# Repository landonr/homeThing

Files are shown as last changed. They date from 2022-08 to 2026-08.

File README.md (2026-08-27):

<h1 align = "center">homeThing Remote ⚙️</h1>
<h5 align = "center">(esphome remote)</h1>
<p align="center">


</p>

#### homeThing is a collection of software and hardware for creating universal remotes that control smart home devices.
There are 3 components that belong to homeThing: the case and circuit board, the menu system code, and the code to control smart home devices
- <a href="#hardware-">Hardware specific for smart home remotes that's open source, customizable, and 3D printable.</a>
- <a href="#homething-menu-">Menu system for ESP32 devices focused on controlling smart home devices similar to an iPod's menu.</a>
- [ESPHome Components for controlling Home Assistant devices.](https://github.com/landonr/esphome-components)

<br>
<div align="center">
	<h2><a href="https://github.com/landonr/homething-c6">Check out the next-generation homeThing C6</a></h2>
</div>
<br>

### Learn More
 - [Get Started](GettingStarted.md) - Learn how to build your own remote
 - [Discord](https://discord.gg/BX6ZtGKHTy) - support / chat with the community and the team
 - [Instagram](https://www.instagram.com/homething.io/) - Follow us on Instagram for updates and new products
 - [Website](https://homething.io) - Check out our website for more information

<div align="center">
	<h3>
	<a href="https://youtu.be/5bx5w-n5c0Y">
		Demo Video
		<br>Demo Video - Watch on YouTube 🎬
	</a>
	</h3>
</div>

# Hardware 💪
We designed the two remotes below to be ideal for controlling smart home devices without a touch screen. They are both battery-powered but can also be plugged into USB and left in one place. The first remote was based on a Lilygo TDisplay. We moved on to building the homeThing S3 because the original device had slow performance, lacked buttons, and had challenges with assembly.
<table>
  <tr>
    <th>
	    <h3>TDisplay homeThing</h3>
    </th>
    <th>
	    <h3>TDisplay S3 homeThing</h3>
	    <a href="https://github.com/landonr/homeThing/tree/main/Case%20Design/tdisplay-s3">More Info</a><br>
    </th>
  </tr>
  <tr>
    <td></td>
    <td></td>

  </tr>
  <tr>
	  <td>Not available for purchase</td>
	  <td><a href="https://homething.io/Buy">Buy fully assembled, ships within 3 business days from 🇨🇦</a></td>
  </tr>
  <tr>
    <td><a href="https://www.pcbway.com/project/shareproject/homeThing_V1_3_e3572f8f.html">Order Case from PCBWay</a></td>
    <td>
      <a href="https://www.pcbway.com/project/shareproject/homeThing_S3_2b3ac3ac.html">Order parts or fully assembled from PCBWay</a>
    </td>
  </tr>
  <tr>
    <td><a href="https://github.com/landonr/homeThing/tree/main/Case%20Design">Case 3D Files</a></td>
    <td><a href="https://github.com/landonr/homeThing/tree/main/Case%20Design">Case 3D Files</a></td>
  </tr>
  <tr>
    <td><a href="tdisplay-ipod.yaml">ESPHome Config</a></td>
    <td><a href="tdisplay-s3.yaml">ESPHome Config</a></td>
  </tr>
  <tr>
  	<td>
	<h4>Features</h4>
	<ul>
		<li>Based on Lilygo TTGo TDisplay, an ESP32 with integrated screen
		<li>Low cost remote with minimal parts</li>
		<li>Scroll wheel and 2 configurable buttons</li>
		<li>USB-C Charging</li>
		<li>3D Printable case with 3 parts</li>
	</ul>
	</td>
  	<td>
	<h4>Features</h4>
	<ul>
		<li>Based on Lilygo TDisplay S3, an ESP32 S3 with integrated screen</li>
		<li>Faster processor and larger display</li>
		<li>Custom PCB for easier setup</li>
		<li>IR Blaster for controlling infrared devices</li>
		<li>Interal microphone for Voice Assistant</li>
		<li>Scroll wheel and 5 configurable buttons</li>
		<li>USB-C Charging</li>
		<li>3D Printable case with 2 parts</li>
	</ul>
	</td>
  </tr>
</table>

We made a couple of custom devices for running homeThing, but it can also run on almost any ESP32 such as,
- M5Stack Fire
- M5Stick C
- Lilygo T-Display T4
- Lilygo T-Display TTGO
- Lilygo T-Display S3
# homeThing Menu 📝
### ESPHome menu system that requires minimal config. Features apps which have custom UIs
|t-display demo|m5stack fire demo|lilygo T4 demo|
|--|--|--|
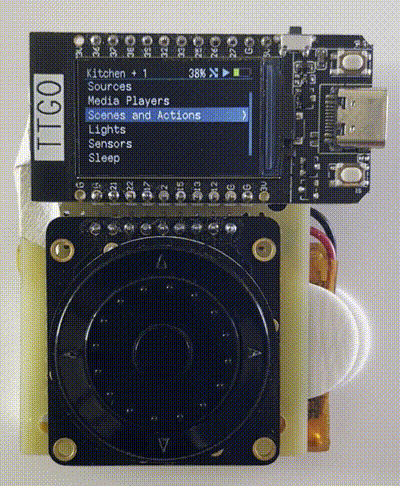
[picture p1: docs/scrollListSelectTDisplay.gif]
Scroll Demo Gif
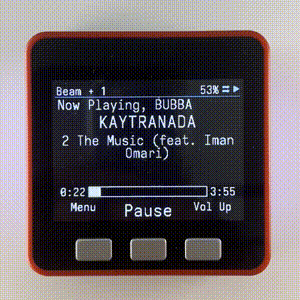
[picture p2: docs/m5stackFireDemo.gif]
Scroll List Fire Demo Gif
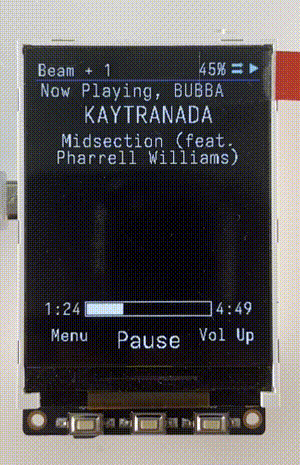
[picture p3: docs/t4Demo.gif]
Lilygo T4 Demo
|||

- Scroll through list and press center to select
- With a scrollwheel the top button goes back
- On M5Stack going up past the top of the list will go back
- A scroll bar appears if list extends past the screen. 
- Screen returns to now playing after display sleeps
    - Display sleeps after 10s of idle. Device sleeps after 2h of idle 💤
- Font size and UI size is adjustable in yaml 🔨
- Simple yaml configuration. all of the complicated code is included in other files 🛠
- Header is always shown at the top with info about the current state

## Apps
### Now playing screen ⏯
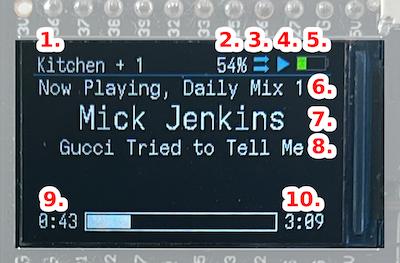
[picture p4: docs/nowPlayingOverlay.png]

<ul>
<li>Control media players using the scroll wheel buttons</li>
<li>Scroll for volume using the scroll wheel</li>
</ul>

|Music|TV|
|--|--|
|<ul><li>Control smart speakers like Sonos, Spotify, or Google Home</li><li>Change source from Spotify playlists, Sonos Favorites, and custom lists</li><li>Manage speaker groups</li></ul>|<ul><li>Menu navigation such as up, down, left, right, select (with scroll wheel)</li><li>Power, back, home, pause in second menu</li><li>Change source from tv source list</li><li>Optional soundbar support</li></ul>|

### IR Remote
<ul>
<li>Custom UI and buttons to control infrared cat toys</li>
</ul>

### Games
<ul>
<li>Snake</li>
<li>Breakout</li>
</ul>

# Mentions
- Home Assistant Voice Contest - Best Starting Guide https://www.home-assistant.io/blog/2024/03/16/voice-assistant-community-contest-winners-annoucement/
- Hackaday https://hackaday.com/2022/09/08/scroll-through-esphome-with-ipod-style-click-wheel/
- Hackster https://www.hackster.io/news/ipod-style-esphome-remote-3ca38edab2b4
- Reddit post https://www.reddit.com/r/homeassistant/comments/x59dcp/i_built_an_ipod_style_esphome_remote_for_home/
- Self Hosted - Episode 80 - Solving Whole Home Audio (around 30:00) https://selfhosted.show/80 

# Includes
- <a href="https://esphome.io/">ESPHome</a>
- <a href="https://github.com/be5invis/Iosevka">Iosevka Font</a>
- [@ssieb](https://github.com/ssieb)'s <a href="https://github.com/ssieb/custom_components/tree/master/components/ip5306">IP5306 esphome component</a>
- <a href="https://github.com/landonr/esphome-components">homeThing ESPHome Components</a>

# Sponsorship



## [PCBWay](https://pcbway.com/g/Xymq6O "PCBWay") sponsors 3D Printing and PCB assembly costs on this project during the prototyping phase! 
If you are interested in their awesome fabrication services please check them out.&nbsp; They offer 

3D prototyping,&nbsp;PCB design and assembly, as well as CNC metal fabrication.&nbsp; Costs are reasonable and the quality is as good as it gets.&nbsp; Thank you PCBWay for sponsoring us and other fun projects!<br><br>

## [cargo](https://cargo.site/ "cargo.site") sponsors our website!

They make it super easy to keep things pretty and up to date! It’s honestly so much easier than managing our own site, highly recommended!

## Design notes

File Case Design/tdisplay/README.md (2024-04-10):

<table>
  <tr>
    <th>TDisplay homeThing</th>
  </tr>
  <tr>
    <td></td>
  </tr>
  <tr>
    <td><a href="https://www.pcbway.com/project/shareproject/homeThing_V1_3_e3572f8f.html">Order Case from PCBWay</a></td>
  </tr>
  <tr>
    <td><a href="https://github.com/landonr/homeThing/tree/main/Case%20Design">Case 3D Files</a></td>
  </tr>
  <tr>
    <td><a href="tdisplay-ipod.yaml">ESPHome Config</a></td>
  </tr>
  <tr>
  	<td>
	<h4>Features</h4>
	<ul>
	<li>Low cost remote with minimal parts</li>
	<li>Scroll wheel and 2 configurable buttons</li>
	<li>USB-C Charging</li>
	<li>3D Printable case with 3 parts</li>
	</ul>
	</td>
  </tr>
  <tr>
  	<td>
	<h4>Parts</h4>
	<ul>
	<li><a href="https://www.adafruit.com/product/5001">Adafruit ANO Directional Navigation and Scroll Wheel Rotary Encoder</a></li>
	<li><a href="https://www.adafruit.com/product/5221">Adafruit ANO Rotary Navigation Encoder Breakout PCB</a></li>
	<li><a href="https://leeselectronic.com/en/product/88345-battery-rechargeable-li-poly-37v-1100mah-jst-zh.html">1100mah lipo</a></li>
	</ul>
	</td>
  </tr>
</table>

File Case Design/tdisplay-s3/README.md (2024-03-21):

<h2>TDisplay S3 homeThing</h2>

<table>
    <tr>
        <th>TDisplay S3<br>homeThing Case</th>
        <th>homeThing S3<br>Circuit Front</th>
        <th>homeThing S3<br>Circuit Back</th>
    </tr>
        <td>
            
        </td>
        <td>
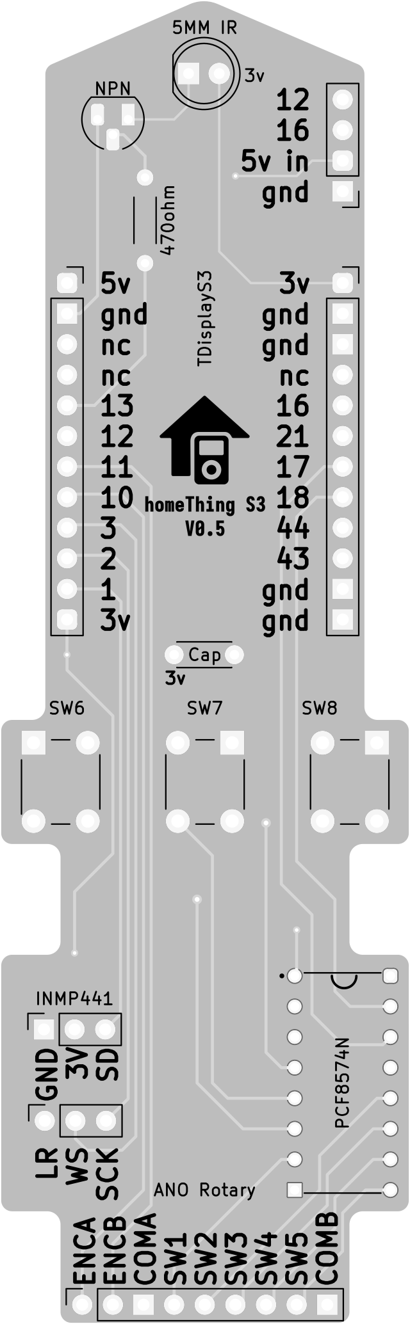
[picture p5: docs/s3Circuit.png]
            
        </td>
        <td>
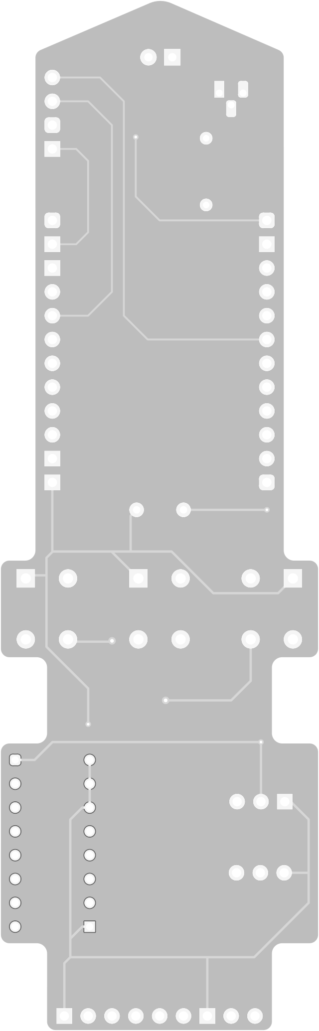
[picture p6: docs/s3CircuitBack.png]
            
        </td>
    </tr>
</table>

<h2>Order</h2>
<a href="https://www.pcbway.com/project/shareproject/homeThing_S3_2b3ac3ac.html">Order Case and PCB from PCBWay</a>

<h2>Case 3D Files</h2>
There's a different file for for the front part FDM printers. This doesn't have extruded buttons so it can print flat without supports
<table>
    <tr>
        <th>Front</th>
        <th>Back</th>
    </tr>
    <tr>
        <td><a href="s3 case front sls.stl">s3 case front sls.stl</a></td>
        <td><a href="s3 case back.stl">s3 case back.stl</a></td>
    </tr>
    <tr>
        <td><a href="s3 case front fdm.stl">s3 case front fdm.stl</a></td>
    </tr>
</table>

<h2>Circuit</h2>
<a href="gerber/">Gerber Files</a>

<h2>ESPHome Config</h2>
<a href="tdisplay-s3.yaml">tdisplay-s3.yaml</a>

<h2>Parts</h2>
<table>
    <tr>
        <th>Name</th>
        <th>Description</th>
    </tr>
    <tr>
        <td><a href="https://www.adafruit.com/product/5221">Custom PCB</a></td>
        <td>Custom PCB for TDisplay S3</td>
    </tr>
    <tr>
        <td><a href="https://www.lilygo.cc/en-ca/products/t-display-s3?variant=42351558590645">TDisplay S3 (Soldered Pin)</a></td>
        <td>TDisplay S3 with soldered pin</td>
    </tr>
    <tr>
        <td><a href="https://www.adafruit.com/product/5001">Adafruit ANO Directional Navigation and Scroll Wheel Rotary Encoder</a></td>
        <td>Directional navigation and scroll wheel rotary encoder</td>
    </tr>
    <tr>
        <td><a href="https://www.adafruit.com/product/5221">Adafruit ANO Rotary Navigation Encoder Breakout PCB</a></td>
        <td>Rotary navigation encoder breakout PCB</td>
    </tr>
    <tr>
        <td><a href="https://www.aliexpress.us/item/32962426410.html">INMP441</a></td>
        <td>INMP441 i2s Microphone</td>
    </tr>
    <tr>
        <td><a href="https://leeselectronic.com/en/product/71446-ic-i-o-expander-for-i2c-8bit-pcf8574p.html">PCF8574n</a></td>
        <td>GPIO extender for I2C 8-bit</td>
    </tr>
    <tr>
        <td><a href="https://leeselectronic.com/en/product/91581-91581RESISTORS14W470OHM110PCS.html">470ohm resistor</a></td>
        <td>470ohm resistor</td>
    </tr>
    <tr>
        <td><a href="https://leeselectronic.com/en/product/844-polyester-cap-50v-01uf-4pcs.html">0.1uF capacitor</a></td>
        <td>0.1uF capacitor</td>
    </tr>
    <tr>
        <td><a href="https://www.aliexpress.com/item/32835179410.html">3.7V 7x20x50mm 700mAh Lipo</a></td>
        <td>3.7V 7x20x50mm 700mAh Lipo</td>
    </tr>
    <tr>
        <td><a href="https://leeselectronic.com/en/product/31231-tack-switch-6x6x10mm.html">10mm Push Button</a></td>
        <td>10mm Push Button</td>
    </tr>
    <tr>
        <td><a href="https://leeselectronic.com/en/product/6049-6049BOLTM25100PCS.html">M2.5x8mm screws</a></td>
        <td>M2.5x8mm screws</td>
    </tr>
    <tr>
        <td><a href="https://leeselectronic.com/qc/product/7174-7174TRANSISTOR2N2222MPS2222ANPN5.html">2N2222 Transistor</a></td>
        <td>2N2222 Transistor</td>
    </tr>
</table>

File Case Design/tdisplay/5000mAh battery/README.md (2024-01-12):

# 3D Case Design
## _Designed to fit a 5000 mAh battery_

Main components can be seen in the "main components.jpg" photo.
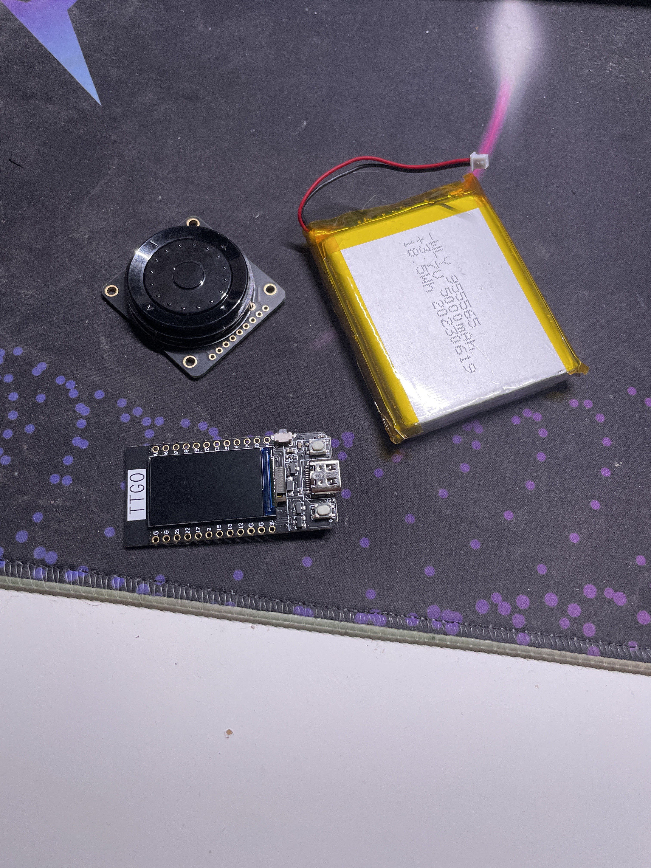
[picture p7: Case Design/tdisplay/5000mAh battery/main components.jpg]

Components list:
- 5000 mAh battery (check the form factor in "main components.jpg" photo; it was bought from a local store so i'm note sure a link would be useful)
- Lilygo T-Display TTGO
- Adafruit ANO Directional Navigation and Scroll Wheel Rotary Encoder [https://www.adafruit.com/product/5001]
- Adafruit ANO Rotary Navigation Encoder Breakout PCB [https://www.adafruit.com/product/5221]

## Details

- Based on the original board mount & buttons from here [https://github.com/landonr/homeThing/tree/main/Case%20Design/tdisplay], hence I added the same buttons file
- The case from the images was printed on an FDM printer in glow-in-the-dark PLA(Ender 3 v2); I assume it can also be printed on a SLA printer

## Print settings

| Setting | value |
| --- | --- |
| Rafts | no |
| Supports | no - for the case parts / yes - only for the buttons, which were printed face down with the face that will be touched by the user |
| Resolution | 0.12 mm |
| Infill | 40% |
| Speed | 75 mm/s |
| Outer wall speed | 37.5 mm/s |
| Inner wall speed | 50 mm/s |
| Wall line count | 4 - do not decrease this! otherwise the curvature of the case will look bad |

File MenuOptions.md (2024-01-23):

# Yaml options for homeThing

## Display State
[Display State is a separate component so that it can be reused. It needs to be included separately, full readme](https://github.com/landonr/homeThing/tree/main/components/homeThingDisplayState)
### Required
- **font_small**: required - id of the small font
- **font_medium**: required - id of the medium font
- **font_large**: required - id of the large font
- **font_large_heavy**: required - id of the large heavy font
- **font_material_large**: required - id of the large material font icons
- **font_material_small**: required - id of the small material font icons

### Optional
- **launch_image**: optional - image to display on boot
- **header_height**: optional - height of header, default 16
- **margin_size**: optional - margin size, default 4
- **bottom_bar_margin**: optional - bottom bar margin, default 1
- **slider_margin_size**: optional - slider margin size (used for rgb lights), default 8
- **icon_size**: optional - icon size, default 18
- **scroll_bar_width**: optional - scroll bar width, default 6
- **font_size_width_ratio**: optional - font size height/width ratio, default 0.6
- **draw_shuffle**: optional - draw shuffle icon, default on (on, off, always)
- **draw_repeat**: optional - draw repeat icon, default on (on, off, always)
- **draw_header_time**: optional - draw time in header, default true
- **draw_battery_level**: optional - draw battery level in header, default false
- **dark_mode**: optional - dark mode (black background), default true
- **draw_volume_level**: optional - draw volume level in header, default false
- **draw_now_playing_bottom_menu**: optional - draw bottom menu on now playing, default false
- **boot_device_name**: optional - boot device name, default homeThing
- **colors**: optional - color palette
  - **gray_dark**: optional - dark gray (default 102, 102, 102)
  - **gray_dark_2**: optional - dark gray 2 (default 20, 20, 20)
  - **gray**: optional - gray (default 25, 25, 25)
  - **accent_primary**: optional - accent primary (default 0, 114, 165)
  - **blue**: optional - blue (default 0, 0, 255)
  - **green**: optional - green (default 0, 255, 0)
  - **black**: optional - black (default 0, 0, 0)
  - **white**: optional - white (default 255, 255, 255)
  - **pink**: optional - pink (default 255, 40, 255)
  - **red**: optional - red (default 255, 0, 0)
  - **yellow**: optional - yellow (default 255, 191, 25)

## Menu
### Required
- **display**: required - id of the display, used to draw display
- **display_state**: required - id of the display setup

### Optional
- **settings**: optional - more menu settings
  - **mode**: required - rotary - 3 button - 2 button
  - **display_timeout**: optional - seconds until screen fades out. default 16
  - **sleep_after**: optional - seconds until device sleeps. default 3600
  - **menu_rollover_on**: optional - menu rolls back to top if you scroll past to bottom
  - **lock_after**: optional - seconds until device locks. default 0 (no lock)
- **sleep_switch**: optional - allows the device to sleep itself
- **battery**: optional - shows battery life
- **backlight**: optional - allows the device to turn off backlight
- **header**: optional - shows a header on top of menu
  - **time_id**: optional - id of time entity
- **menu_display**: optional - customize display drawing
- **apps**: optional - downloadable apps
- **boot**: optional - customize boot settings
  - **api_connected**: optional - shows whether device is connected to home assistant
  - **media_player_group**: optional - waits for media players to load before entering menu  
- **on_redraw**: optional - automation to redraw display
- **home_screen**: optional - customize entities on home screen
- **screens**: optional - custom screens for entities

## Example of a customized yaml
```yaml

homeThingDisplayState:
    id: homeThingDisplayState # required
    font_small: font_small # required
    font_medium: font_medium # required
    font_large: font_large # required
    font_large_heavy: font_large_heavy # required
    font_material_large: font_material_large # required
    font_material_small: font_material_small # required
    header_height: 16
    margin_size: 4
    bottom_bar_margin: 1
    slider_margin_size: 8
    icon_size: 18
    scroll_bar_width: 6
    font_size_width_ratio: 0.6
    draw_shuffle: on # optional (on, off, always)
    draw_repeat: on # optional (on, off, always)
    draw_header_time: True
    draw_battery_level: False
    dark_mode: True
    draw_volume_level: False
    draw_now_playing_bottom_menu: False
    boot_device_name: homeThing
    colors:
      gray_dark: gray_dark
      gray_dark_2: gray_dark_2
      gray: gray
      accent_primary: accent_primary
      blue: blue
      green: green
      black: black
      white: white
      pink: pink
      red: red
      yellow: yellow

homeThing:
  id: homeThingMenu
  display: my_display
  display_state: display_state_id
  settings:
    mode: rotary
    display_timeout: 16
    sleep_after: 3600
    menu_rollover_on: False
    lock_after: 0
  sleep_switch: sleep_toggle
  battery:
    battery_percent: battery_percent
    charging: charging
  backlight: backlight
  header:
    time_id: time_id
  apps:
    - now_playing
  boot:
    api_connected: api_connected
    media_player_group: media_player_group
  on_redraw:
    then:
      component.update: my_display
  home_screen:
    - type: light
      id: light_all_lights
  screens:
    - name: Desk Screen
      entities:
        - type: cover
          id: cover_megadesk
        - type: number
          id: desk_height_number
        - type: command
          name: "desk nudge up"
          command:
            - homeassistant.service:
                service: button.press
                data:
                  entity_id: "button.desk_position_nudge_up"
        - type: command
          name: "desk nudge down"
          command:
            - homeassistant.service:
                service: button.press
                data:
                  entity_id: "button.desk_position_nudge_down"
        - id: light_desk_lamp
          type: light
    - name: Lights Screen
      entities:
        - id: light_all_lights
          type: light
        - type: command
          name: "color lights"
          command:
            - homeassistant.service:
                service: script.colors
        - type: command
          name: "lights off"
          command:
            - homeassistant.service:
                service: script.off_script
    - name: Settings Screen
      show_version: True
      entities:
        - id: backlight
          type: light
        - id: "restart_switch"
          type: switch
        - id: wifi_ssid
          type: text_sensor
        - id: wifi_signal_percent
          type: sensor
        - id: wifi_ip
          type: text_sensor
```

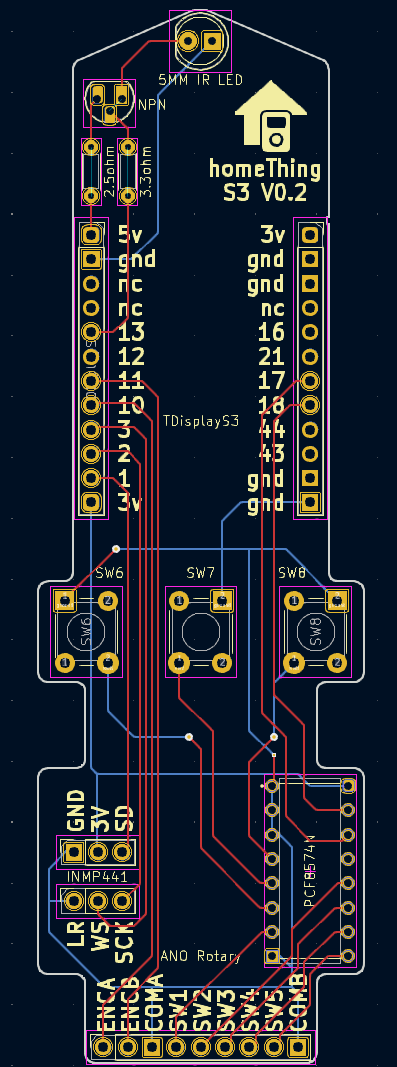
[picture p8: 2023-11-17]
Case Design/tdisplay-s3/s3-circuit.png

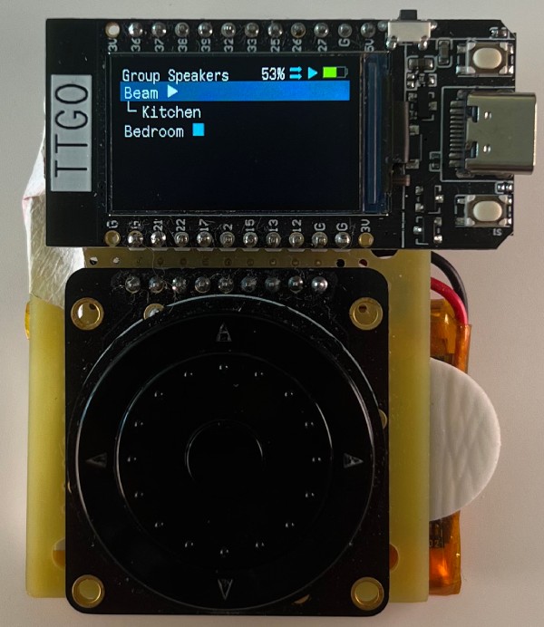
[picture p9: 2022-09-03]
docs/group.jpg

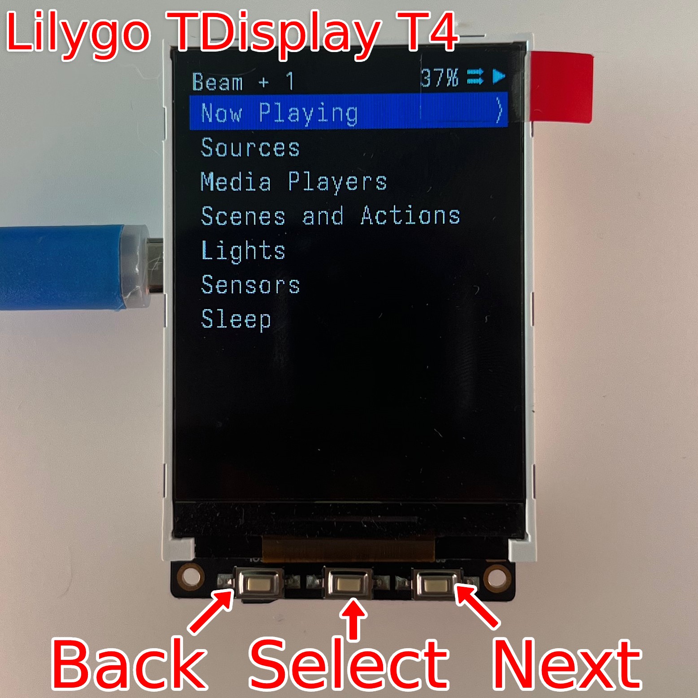
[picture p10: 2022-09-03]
docs/tdisplayT4.jpg

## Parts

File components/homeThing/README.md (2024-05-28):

# HomeThing Menu Configuration Guide

This README provides an overview of the configuration options for the `HomeThingMenuBase` custom component in ESPHome. This setup example configures a device using the LilyGo T-Display S3 with various apps, settings, and menu screens for an interactive display interface.

**For the full configuration file, please refer to the [example configuration](https://github.com/landonr/homeThing/blob/main/tdisplay-s3.yaml).**

## Configuration Options

### **homeThing**

#### General Options
- **id**: `string`
  - Unique ID for the HomeThing component.
- **apps**: `list`
  - List of applications available on the menu.
  - [See the full list of apps](../) 
- **settings**: `map`
  - **Optional**, Configuration for device behavior and display.
  - **sleep_after**: `int`
    - Time (in seconds) before the device goes to sleep.
  - **display_timeout_while_charging**: `int`
    - Time (in seconds) for display timeout while charging.
  - **idle_app**: `string`
    - Default application when the device is idle.
  - **max_brightness**: `float`
    - Maximum brightness level.
- **backlight**: `Light`
  - ID of the backlight component.
- **header**: `map`
  - Configuration for the display header.
- **battery**: `map`
  - Configuration for battery monitoring.
  - **charging**: `BinarySensor`
    - ID of the binary sensor that indicates whether the device is currently charging.
  - **battery_percent**: `Sensor`
    - ID of the sensor that monitors the battery percentage.
- **display**: `string`
  - ID of the display component.
- **on_redraw**: `action`
  - Actions to perform when the display is redrawn.
  - example 
    ```yaml
    homeThing:
      ...
      on_redraw:
      then:
        component.update: my_display
- **display_state**: `string`
  - ID of the display state component.
  - [Link to Display State Configuration Guide](https://github.com/landonr/homeThing/blob/main/components/homeThingDisplayState/README.md)
- **boot**: `map`
  - **Optional**, Configuration for actions during device boot.
  - **api_connected**: `BinarySensor`
      - ID of the API connected sensor that the boot screen will wait for.
  - **media_players_loaded**: `BinarySensor`
      - ID of the media players loaded sensor that the boot screen will wait for.
  - **launch_image**: `Image`
      - ID of the launch image.
- **home_screen**: `map`
  - Configuration for the main home screen.
  - example:
    ```yaml
    homeThing:
      ...
      home_screen:
        name: homeThing
        entities:
          - id: cat_max_servings
            type: number
- **screens**: `list`
  - Configuration for additional screens.
  - example:
    ```yaml
    homeThing:
      ...
      screens:
        - name: Desk Screen
          entities:
            - id: light_desk_lamp
              type: light

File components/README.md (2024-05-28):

# homeThing Components

## Components

- [homeThing](./homeThing) - Main repository for homeThing.
- [homeThingApp](./homeThingApp) - Application base for homeThing.
- [homeThingAppBreakout](./homeThingAppBreakout) - Breakout game for homeThingApp.
- [homeThingAppCatToy](./homeThingAppCatToy) - Cat toy IR remote app for homeThingApp.
- [homeThingAppNowPlaying](./homeThingAppNowPlaying) - Now playing app for homeThingApp.
- [homeThingAppSnake](./homeThingAppSnake) - Snake game for homeThingApp.
- [homeThingAppWeather](./homeThingAppWeather) - Weather app for homeThingApp.
- [homeThingDisplayState](./homeThingDisplayState) - Display state component for homeThing.

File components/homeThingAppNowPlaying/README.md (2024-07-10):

# HomeThingMenuNowPlayingControl Component

The `HomeThingMenuNowPlayingControl` component for ESPHome integrates with HomeThing and allows you to display a "Now Playing" screen for a group of media players. It provides options to show the currently playing media, control playback, and customize the display.

Can be used in the [homeThing](https://github.com/landonr/homeThing) menu system.

## Base Configuration

The `HomeThingMenuNowPlayingControl` component has several base configuration options. By default, appropriate values will be chosen for all of these options, but you can override them if you want to.

### Example Configuration

```yaml
# Example HomeThingMenuNowPlayingControl configuration
homeThingAppNowPlaying:
  id: now_playing
  display: my_display
  display_state: display_state_id
  media_player_group: media_group_component
  now_playing_image: media_player_image
```

### Notes

- The `now_playing_image` component should be configured if you want to display an image for the currently playing media. [Now Playing image info](../../common/nowPlayingImage.yaml)
- The bottom menu is useful for remotes with a limited number of buttons.

## Configuration Details

#### Configuration Variables

- **id** *(Required, string)*: Manually specify the ID for code generation.
- **display** *(Required)*: The display buffer to use.
- **display_state** *(Required)*: The display state to use. [Display state info](../homeThingDisplayState)
- **media_player_group** *(Required)*: The ID of the `HomeAssistantMediaPlayerGroup` component to use. [Media player group info](https://github.com/landonr/esphome-components/tree/main/components/homeassistant_media_player)
- **now_playing_image** *(Optional)*: The ID of the image to display for the currently playing media. [Now Playing image info](../../common/nowPlayingImage.yaml)
- **draw_bottom_menu** *(Optional, boolean)*: Whether to draw the bottom menu on the display. Defaults to `false`.

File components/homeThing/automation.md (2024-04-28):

# homeThing Actions

## Menu Actions

### homething_menu.up Action
Go up in the menu, or up on a TV

```yaml
on_...
  then:
    - homething_menu.up: homeThingMenu
```

### homething_menu.down Action
Play/Pause media player, or go down on a TV

```yaml
on_...
  then:
    - homething_menu.down: homeThingMenu
```

### homething_menu.left Action
Previous track on media player, or go left on a TV

```yaml
on_...
  then:
    - homething_menu.left: homeThingMenu
```

### homething_menu.right Action
Next track on media player, or go right on a TV

```yaml
on_...
  then:
    - homething_menu.right: homeThingMenu
```

### homething_menu.select Action
Select the current menu item

```yaml
on_...
  then:
    - homething_menu.select: homeThingMenu
```

### homething_menu.scroll_clockwise Action
Move the menu cursor down, volume up

```yaml
on_...
  then:
    - homething_menu.scroll_clockwise: homeThingMenu
```

### homething_menu.scroll_counter_clockwise Action
Move the menu cursor up, volume down

```yaml
on_...
  then:
    - homething_menu.scroll_counter_clockwise: homeThingMenu
```

### homething_menu.back Action
Go back in the menu

```yaml
on_...
  then:
    - homething_menu.back: homeThingMenu
```

### homething_menu.option Action
Open the options menu

```yaml
on_...
  then:
    - homething_menu.option: homeThingMenu
```

### homething_menu.home Action
Go to the home screen

```yaml
on_...
  then:
    - homething_menu.home: homeThingMenu
```

## Notification Actions

### homething_menu.clear_notifications Action
Clears any existing notifications from homething_menu.

```yaml
on_...
  then:
    - homething_menu.clear_notifications: homeThingMenu
```

### homething_menu.add_notification Action
Adds a new notification
- **Title**: Text shown in notification header
- **Subtitle**: Text shown at the top of the content of notification
- **Message**: Text shown in content of notification
- **Persistent**: Notification stays on screen after screen lock (Optional: default false, set to true for a persistent notification)

```yaml
on_...
  then:
    - homething_menu.add_notification: 
        title: "Notification Title"
        subtitle: "Notification Subtitle"
        message: "Notification Message
        persistent: true
```

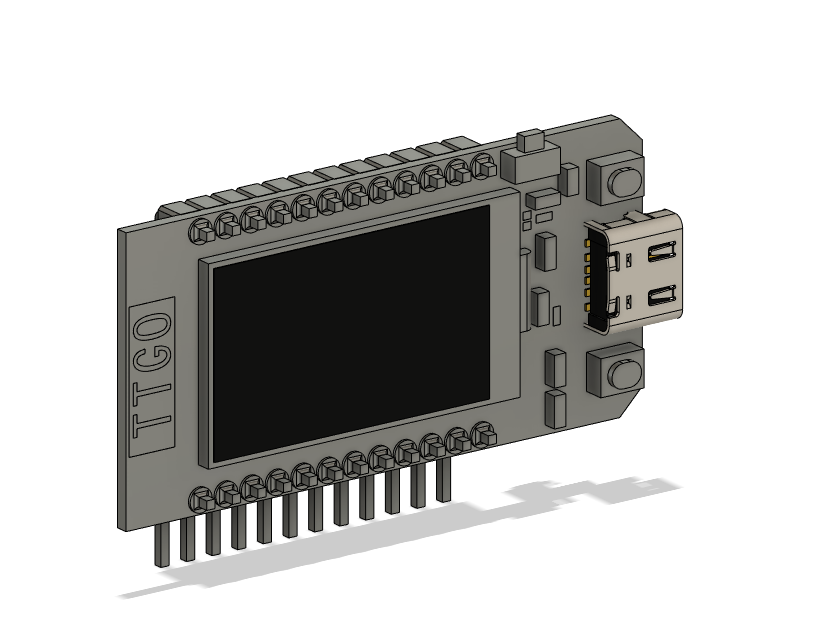
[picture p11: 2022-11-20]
Case Design/components/TTGO.png

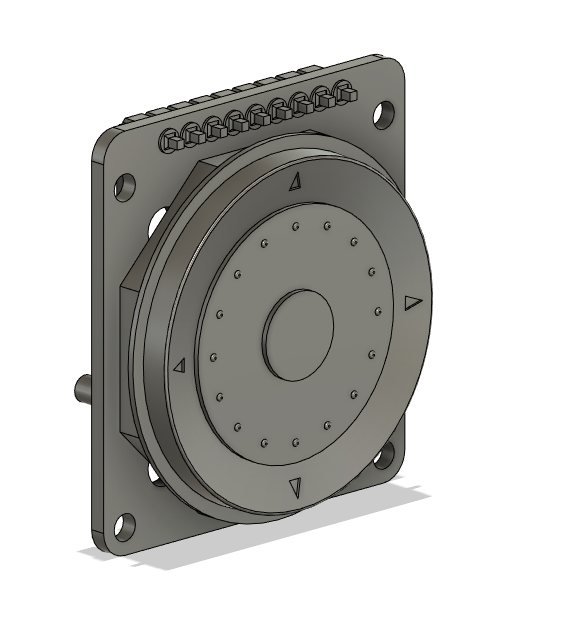
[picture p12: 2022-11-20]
Case Design/components/Rotary Encoder.png

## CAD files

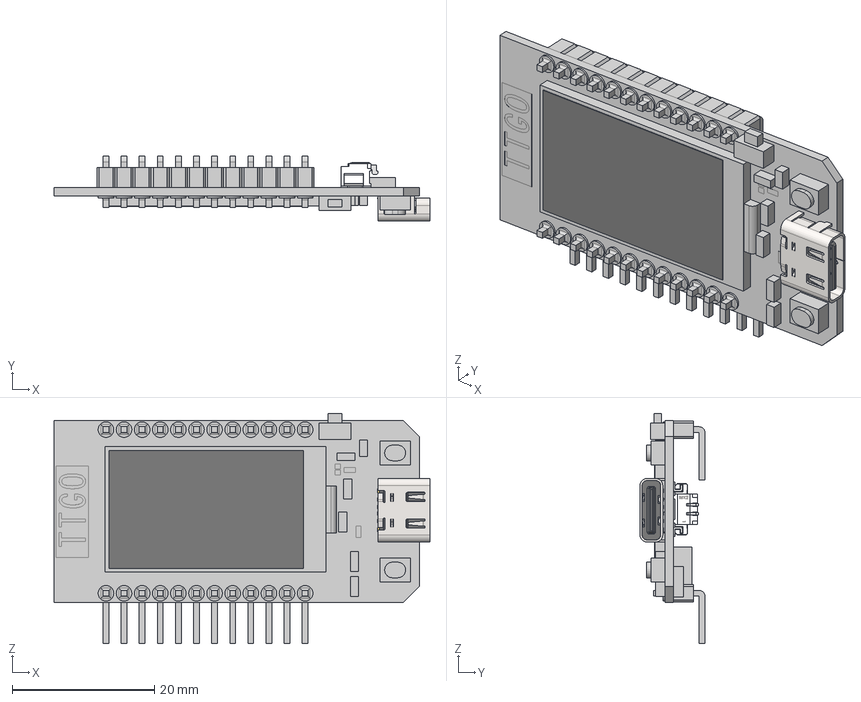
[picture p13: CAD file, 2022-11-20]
Case Design/components/TTGO.step
52.8 x 9.15 x 32.4 mm
USB Connector Type C female 6pin v1
MOLEX1.25-WS-引脚 x 2
LOGO?0.25
MOLEX1.25-WS-2P

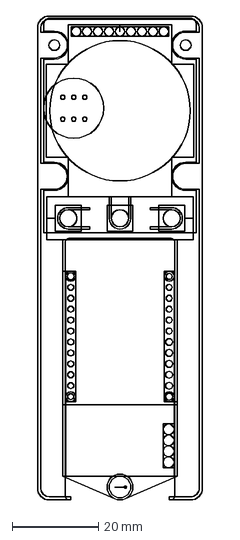
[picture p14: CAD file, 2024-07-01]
Case Design/tdisplay-s3/s3pcb.dxf
38.3 x 112.4 mm

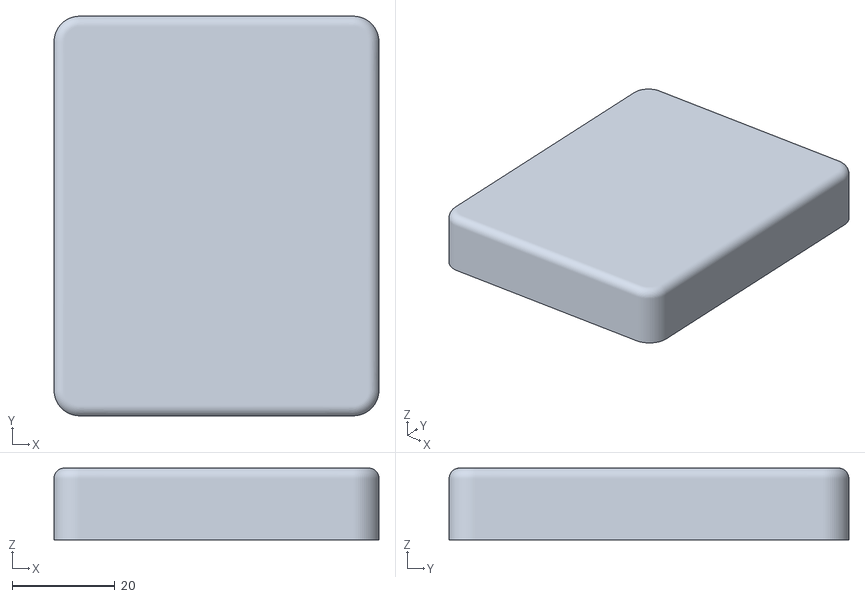
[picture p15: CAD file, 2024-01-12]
Case Design/tdisplay/5000mAh battery/Case_v1.0_--_Back_Case_--_FDM_--5000mAh.stl
63.3 x 77.9 x 14.0

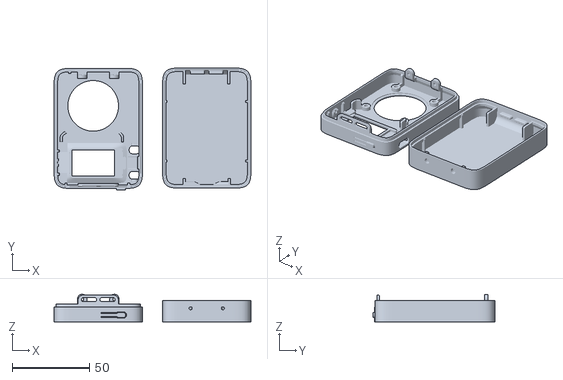
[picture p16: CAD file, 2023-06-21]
Case Design/tdisplay/Jaspercohen_ESP Home Remote 1.3 Bok FDM Edit.stl
127.6 x 79.1 x 17.9

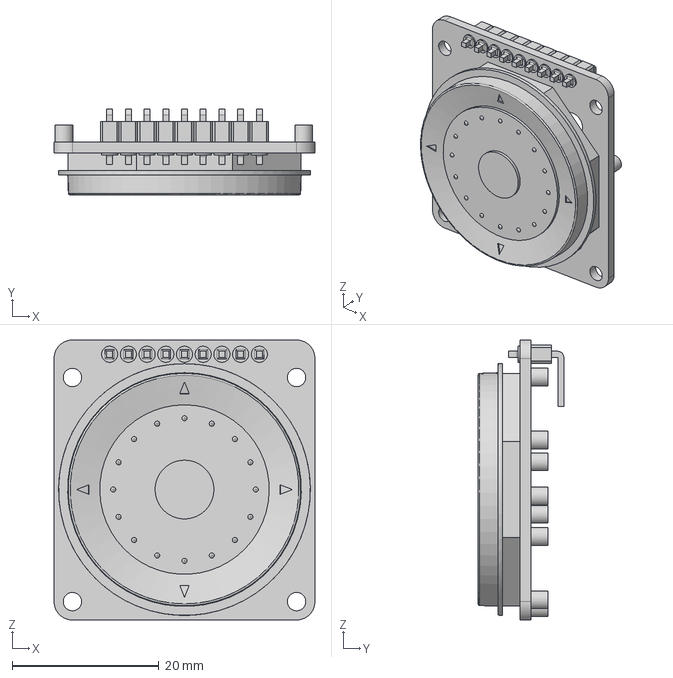
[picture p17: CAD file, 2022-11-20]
Case Design/components/Adafruit Rotary Navigation Encoder.step
35.5 x 11.6 x 38.1 mm

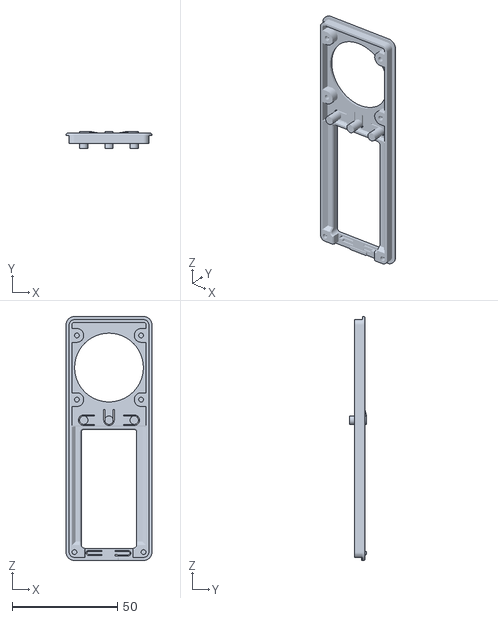
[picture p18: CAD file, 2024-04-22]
Case Design/tdisplay-s3/s3 case front sls.stl
40.8 x 8.15 x 115.9

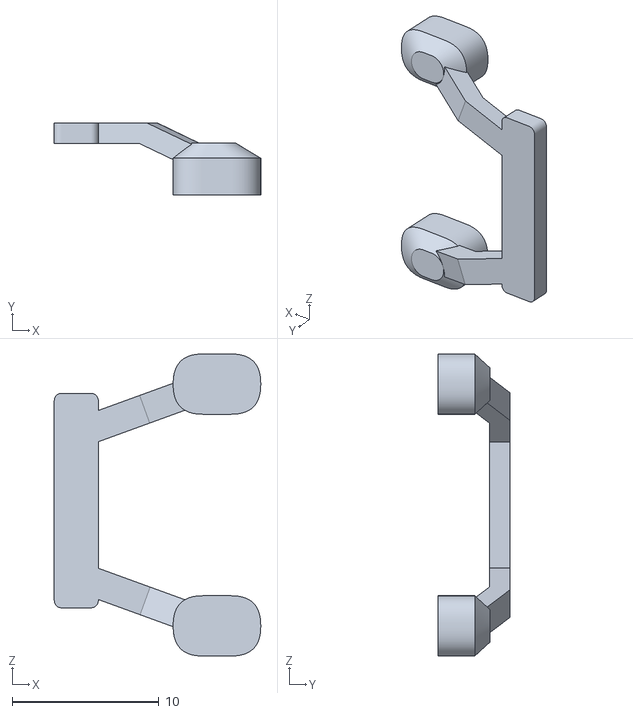
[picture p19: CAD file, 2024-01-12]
Case Design/tdisplay/5000mAh battery/HT--Button Set--SLA -- v1.3.stl
14.1 x 4.89 x 20.5

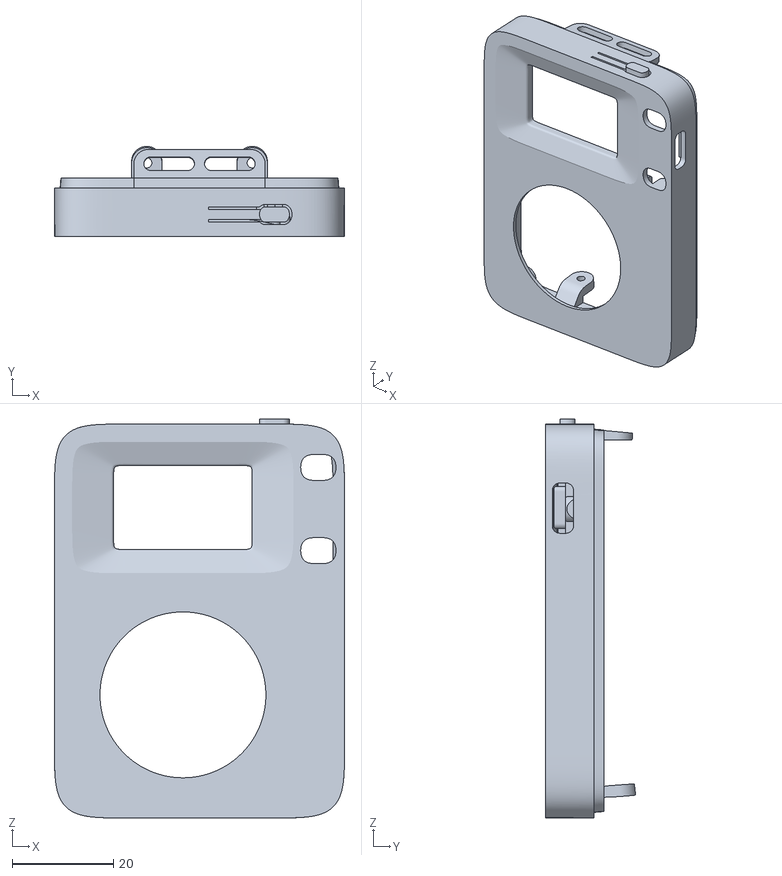
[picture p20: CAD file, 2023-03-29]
Case Design/tdisplay/HT--Front--FDM_--_v1.2.stl
57.4 x 17.9 x 78.9

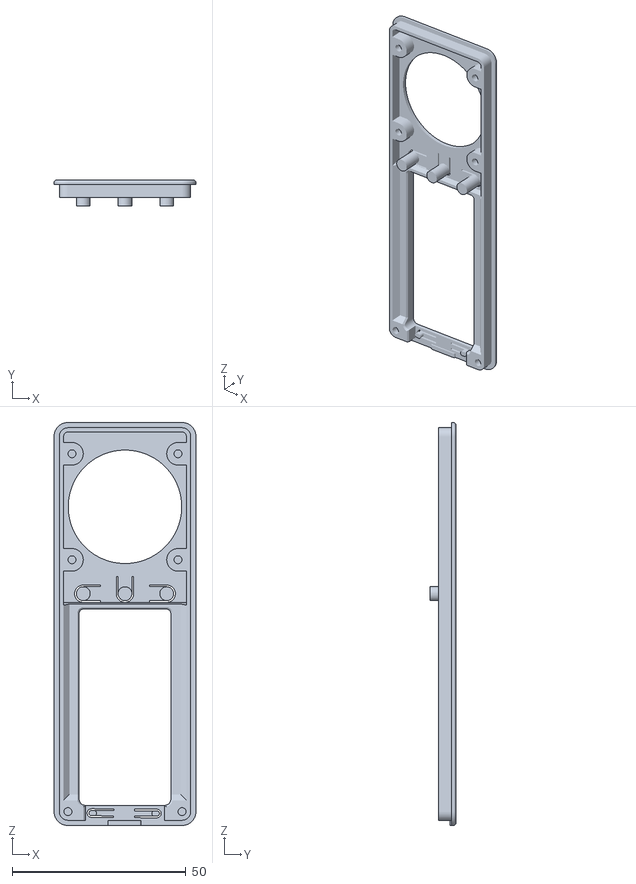
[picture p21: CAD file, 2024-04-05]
Case Design/tdisplay-s3/s3 case front fdm.stl
40.8 x 7.50 x 115.9

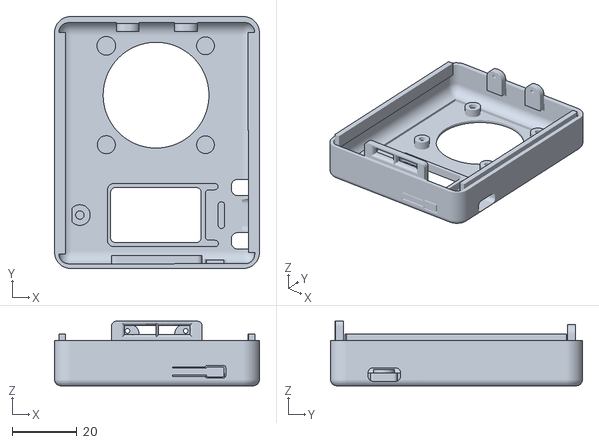
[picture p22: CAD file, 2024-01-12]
Case Design/tdisplay/5000mAh battery/Case_v1.0_--_Front_Case_--_FDM_--5000mAh.stl.stl
63.4 x 77.9 x 20.0

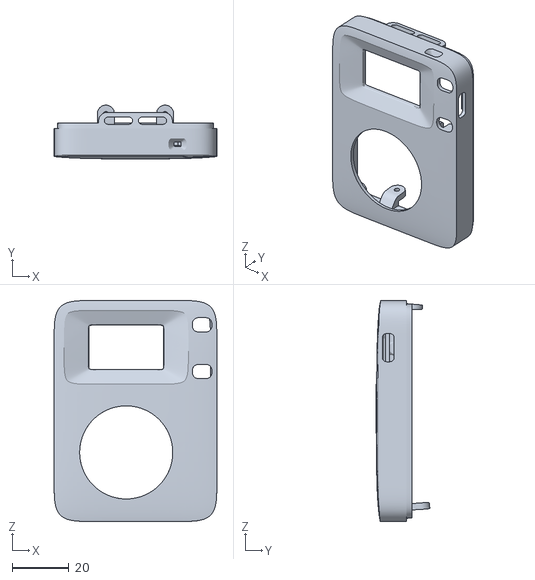
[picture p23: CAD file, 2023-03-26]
Case Design/tdisplay/ESP_v1.1A_Front_Case_-_mm.stl
57.4 x 19.0 x 77.9

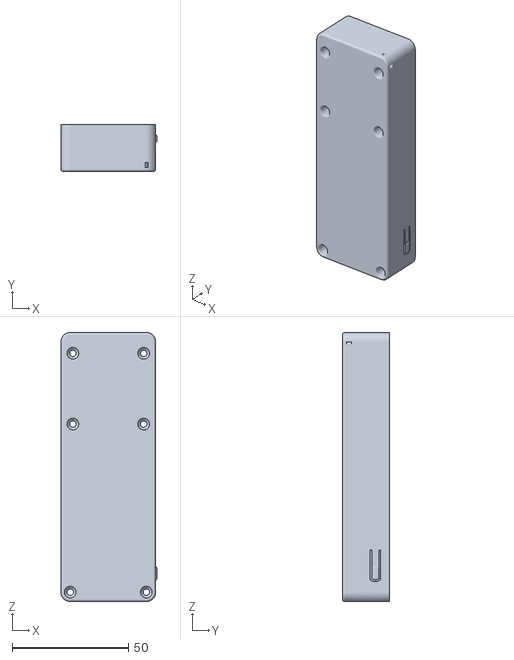
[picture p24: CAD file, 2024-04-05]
Case Design/tdisplay-s3/s3 case back.stl
41.4 x 20.3 x 115.9

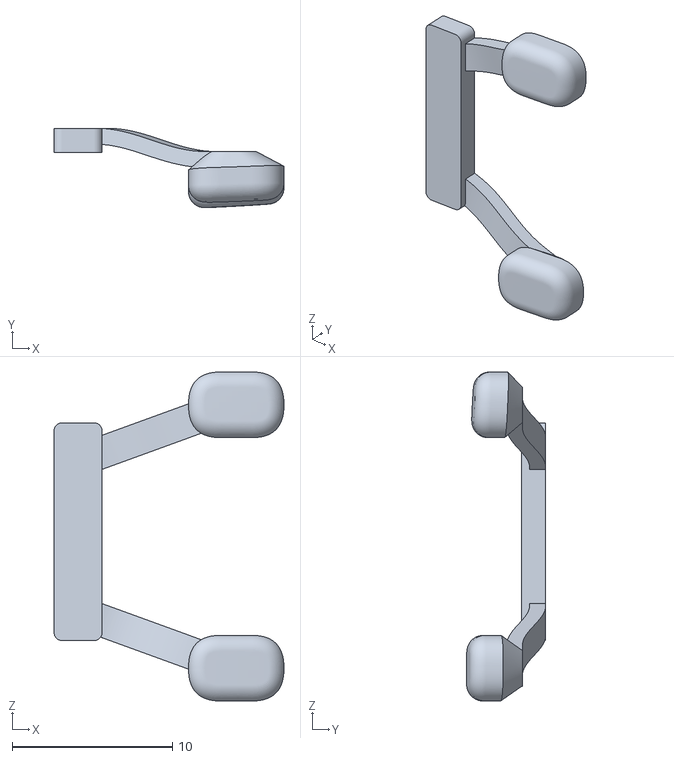
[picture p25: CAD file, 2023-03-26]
Case Design/tdisplay/ESP_v1.1A_Button_Set_-_mm.stl
14.4 x 4.96 x 20.5

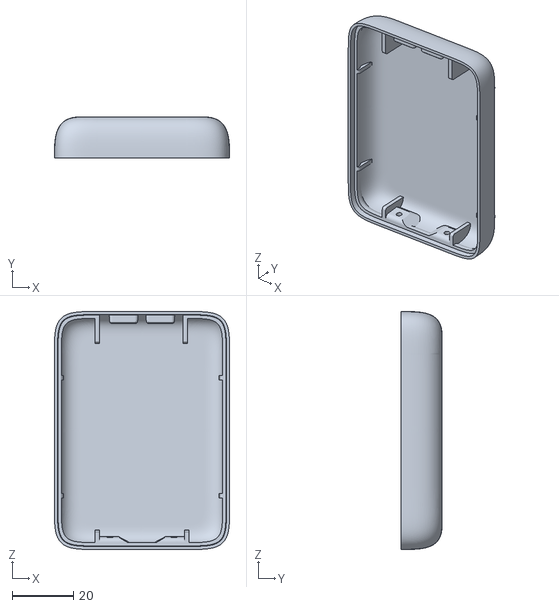
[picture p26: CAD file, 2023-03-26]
Case Design/tdisplay/ESP_v1.1A_Back_Case_-_mm.stl
57.3 x 13.4 x 77.9

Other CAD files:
Case Design/tdisplay/Case_v1.1B_--_Button_Set_--_FDM_--_mm.stl
Case Design/tdisplay/Case_v1.1B_--_Front_Case_--_FDM_--_mm.stl
Case Design/tdisplay/Case_v1.1B_--_Back_Case_--_FDM_--_mm.stl

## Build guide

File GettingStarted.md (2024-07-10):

<h1 align = "center">homeThing: Getting Started 🌈</h1>

<h2 align = "center">
<a href="https://github.com/landonr/homeThing/blob/main/tdisplay-s3.yaml">See a Full Config for TDisplay S3 here 📦</a></h2>

<h1 align="center"><a href="https://www.youtube.com/watch?v=LEmA9E3Gzkk">
	Watch on YouTube!
	<br>
	
</a></h1>

### Required
-  Hardware (pick one):
	- homeThing S3
	- LilyGo T-Display S3
	- LilyGo T-Display
	- LilyGo T-Display T4
	- M5Stack Fire
	- M5Stick C
	- Generic ESP32 + [Supported display](https://esphome.io/components/display/index.html#see-also "Supported display")
- Software:
	- [ESPHome](https://esphome.io/) (required)
	- [Home Assistant](https://www.home-assistant.io/) (required for now, MQTT support is coming soon)
	- [Spotcast](https://github.com/fondberg/spotcast) - [(optional)](#spotcast-setup)
 	- Cairosvg, Pillow, Libmagic (optional)

### 1. Install ESPHome on your hardware
[ESPHome install guide](https://esphome.io/guides/getting_started_hassio.html)
> Note: To use fonts and images in this project, you will need to have the python pillow package installed. If you are running this project as a Home Assistant add-on or with the official ESPHome docker image, the package should already be installed. Otherwise, you can install it using the command `pip install "pillow==10.1.0"`. For more information, refer to the [ESPHome documentation on images](https://esphome.io/components/display/index.html#images).

### 2. Include the homeThing components in your yaml
```yaml
external_components:
  - source: # homeThing, display setup, and now playing app
      type: git
      url: https://github.com/landonr/homeThing
      ref: main
    refresh: 0s
    components: [
      homeThing, 
      homeThingDisplayState,
      homeThingApp, # only required if using apps
      homeThingAppNowPlaying # only required for Now Playing app
    ]
  - source:
      type: git
      url: https://github.com/landonr/esphome-components
      ref: main
    refresh: 0s
    components: [
      homeassistant_component,
      homeassistant_media_player,
      media_player_source,
      media_player_source_sonos,
      media_player_source_spotify,
      media_player_source_custom
    ]
```

### 3. Setup Device
these packages are for a Lilygo TDisplay with a rotary encoder and battery
```yaml
packages:
  remote_package:
    url: https://github.com/landonr/homeThing
    ref: main
    files: [
      common/device_base.yaml, # defines api, ota, free memory and uptime sensor
      common/ipod/lilygo_tdisplay_ipod_backlight.yaml, # used for toggling backlight
      common/ipod/lilygo_tdisplay_ipod_battery.yaml, # used for battery percent
      common/ipod/lilygo_tdisplay_ipod_binary_sensor.yaml, # used for button controls
      common/ipod/lilygo_tdisplay_ipod_rotary.yaml, # used for rotary controls
      common/ipod/lilygo_tdisplay_ipod_sleep.yaml, # required for device to sleep
      common/fonts.yaml, # default font
      common/icon_fonts.yaml # material icons
      common/images.yaml, # boot screen image
    ]
    refresh: 0s
```

### 4. Setup your home config
- detailed information is here https://github.com/landonr/esphome-components
- example

```yaml
switch:
    - platform: homeassistant_component
      entity_id: "switch.oven_fan"
      name: "Oven Fan"
      id: oven_fan_switch

text_sensor:
  - platform: homeassistant
    entity_id: "sensor.vancouver_forecast"
    name: "Weather"
    id: sensor_weather
```

## 5. Music control setup *(Optional)*
 - Set up a [Home Assistant media player](https://github.com/landonr/esphome-components/tree/main/components/homeassistant_media_player/media_player)

 - Set up the [Media Player Group](https://github.com/landonr/esphome-components/tree/main/components/homeassistant_media_player)

 - Set up the [Now Playing app](https://github.com/landonr/homeThing/tree/readme-update/components/homeThingAppNowPlaying)

### 6. Set up the homeThing menu

full config documentation [here](MenuOptions.md)

```yaml
# homeThing config

homeThingDisplayState:
  id: display_state_id
  draw_battery_level: true
  font_small: small_font
  font_medium: medium_font
  font_large: large_font
  font_large_heavy: large_font
  font_material_large: material_font_large
  font_material_small: material_font_small

homeThing:
  id: homeThingMenu
  settings:
    sleep_after: 14400
  boot:
    api_connected: api_connected
    launch_image: launch_image    
  sleep_switch: sleep_toggle
  backlight: backlight
  battery:
    battery_percent: battery_percent
    charging: charging
  display: my_display
  display_state: display_state_id
  apps:
    - now_playing
  on_redraw:
    then:
      component.update: my_display
  home_screen:
    name: homeThing
    entities:
      - type: text_sensor
        id: sensor_weather
  screens:
    - name: Kitchen Screen
      entities:
        - type: switch
          id: oven_fan_switch
```
### 7. Install on your device
- [ESPHome Docker/Addon](https://esphome.io/guides/getting_started_hassio.html)
- [ESPHome Command Line](https://esphome.io/guides/installing_esphome.html)
### 8. Add the device to Home Assistant
- Home Assistant should auto discover the device and send a notification
	- If not, add a ESPHome integration using the ip address of the homeThing device
- Allow API calls from the device by clicking configure on it, then checking the **Allow the device to make Home Assistant service calls** checkbox
### 9. **Done! 🎉**

---

# If you have any trouble with set up, please make an [issue](https://github.com/landonr/homeThing/issues)

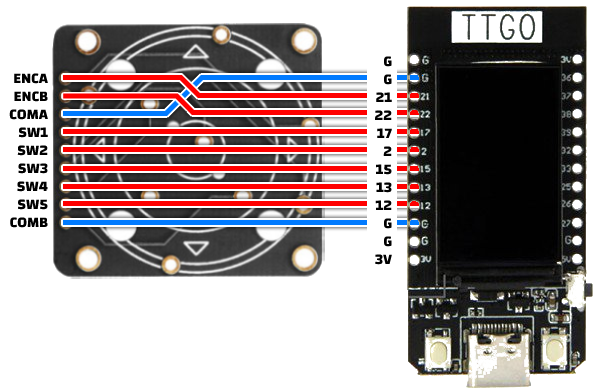
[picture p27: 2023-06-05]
docs/wiring-png.png

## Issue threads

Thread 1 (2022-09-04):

Source code is missing

mshulman, 2022-09-04:
I don’t see the c++ code in the repo, only header files.

Where should I look?

Also, do you have build files checked in?

landonr, 2022-09-05:
its all in the header files. ill make a pr to move it to cpp files

landonr, 2022-09-09:
it wouldn't compile :I. my other esphome projects all include .h files only so it might be how its supposed to be

mshulman, 2022-09-09:
What hardware should I buy to try this?

-ms

On Sep 9, 2022, at 8:12 AM, Lando ***@***.***> wrote:

it wouldn't compile :I. my other esphome projects all include .h files only so it might be how its supposed to be

—
Reply to this email directly, view it on GitHub<https://github.com/landonr/esphome-remote/issues/1#issuecomment-1242105048>, or unsubscribe<https://github.com/notifications/unsubscribe-auth/AALKNBEGLCLTFBLMYMSSXLLV5NHVHANCNFSM6AAAAAAQEFCTV4>.
You are receiving this because you authored the thread.Message ID: ***@***.***>

landonr, 2022-09-10:
https://github.com/landonr/esphome-remote/blob/main/GettingStarted.md#what-you-need

An M5Stack Fire is the easiest because it already has a battery and a case. If you end up going with a Lilygo T4 or TDisplay you can add a rotary scrollwheel using the gpio pins

Pretty much any esp32 + display combo with 2+ buttons that works with ESPHome will work for this project

LuxStatera, 2022-09-27:
Will a D1 mini work?

landonr, 2022-09-27:
I have one but I don't have an extra display. It should, which display are you using?

LuxStatera, 2022-09-27:
I have ordered any parts yet since I wanted to see if I would also need to order an ESP32 or if a D1 mini would work since I already have a few extras

landonr, 2022-09-28:
D1 should work with any display supported by esphome

LuxStatera, 2022-09-28:
Sounds good I'll order some parts. Any plans for a 3D printed case?

landonr, 2022-09-28:
yes it's in progress. hopefully just a few weeks

LuxStatera, 2022-09-28:
You rock!

landonr, 2023-04-02:
fixed in #41

Closed 2023-04-02.

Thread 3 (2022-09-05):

Watchdog triggering on M5Stack Fire

ralfkah, 2022-09-05:
Hey,

I love your project and tried to install it on my M5Stack Fire.
I already tried it 3-4 times, but the software keeps rebooting with a watchdog triggering.
Logs attached. I don't know how to proceed, can you point me in the right direction?
Not sure how to continue with debugging. Already removed most of my HomeAssistant entities (scenes, scripts, lights, ...).

I flashed it via ESPHome Web, not sure if this makes any difference.

Regards
Ralf

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
**> E (26849) task_wdt: Task watchdog got triggered. The following tasks did not reset the watchdog in time:
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

landonr, 2022-09-05:
can you try updating the esphomeRemote.h drawMenu() function with this
`
void drawMenu() {
  if(idleTime > 16) {
    menuDrawing = false;
    return;
  }
  if (speakerGroup -> playerSearchFinished == false) {
    speakerGroup -> findActivePlayer();
    menuDrawing = false;
    // drawBootSequence();
    return;
  }
...
`
the dumb boot sequence might be taking too long to draw

ralfkah, 2022-09-05:
I changed the header file according to your suggestion. Now the device keeps on, seems that your idea was right regarding the boot sequence. But now the screen stays off (black), although I can see button events in the log file, example below:

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

landonr, 2022-09-05:
have you added your device to home assistant in the integrations menu? you might have to set the autoClearState to 1 also
```
void drawMenu() {
  if(idleTime > 16) {
    menuDrawing = false;
    return;
  }
  if (speakerGroup -> playerSearchFinished == false) {
    speakerGroup -> findActivePlayer();
    menuDrawing = false;
    autoClearState = 1;
    // drawBootSequence();
    return;
  }
...
```

ralfkah, 2022-09-06:
Yes, I added it to my local HA instance via the esphome-integration. A couple of switch entities (backlight/remote backlight) appeared, also a battery level sensor and a node status. I also tried deleting and re-adding the fireremote device in HA.

I added the changed code, but still the same result. According to the logs, the software is running and the device is connected to wifi. Display stays dark all the time. As soon as i press a button, the rgb light on the m5stack fire turns on and off again after a while.

I can also see that I can interact with a media_player instance by pressing buttons:
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

When I'm home later today, I will try to debug to find out, what the issue is with my m5stack fire :-)

landonr, 2022-09-06:
we should see some log like **media_player.55_tcl_roku_tv state changed to playing** when the remote finds the tv. this needs to happen before it gets past the boot screen

heres what I see on boot
```
[C][captive_portal:088]: Captive Portal:
[C][mdns:094]: mDNS:
[C][mdns:095]:   Hostname: fireremote
[C][ota:085]: Over-The-Air Updates:
[C][ota:086]:   Address: fireremote.local:3232
[C][api:138]: API Server:
[C][api:139]:   Address: fireremote.local:6053
[C][api:143]:   Using noise encryption: NO
[C][deep_sleep:049]: Setting up Deep Sleep...
[C][deep_sleep:059]:   Wakeup Pin: GPIO39
[D][sensor:127]: 'VBatt': Sending state 1.71500 V with 2 decimals of accuracy
[D][api:102]: Accepted ::FFFF:AC10:143
[D][binary_sensor:036]: 'Node Status': Sending state ON
[D][api.connection:861]: Home Assistant 2022.8.7 (::FFFF:AC10:143): Connected successfully
[D][time:042]: Synchronized time: 2022-09-06 00:18:57
[D][Player:086]: media_player.55_tcl_roku_tv state changed to playing
[D][WARNING:016]: menu already drawing
[D][Player:112]: media_player.55_tcl_roku_tv name changed to 55" TCL Roku TV
[D][light:035]: 'Remote Light' Setting:
[D][light:046]:   State: OFF
[D][light:108]:   Effect: 'None'
[D][light:035]: 'Remote Light' Setting:
[D][light:046]:   State: ON
[D][light:050]:   Brightness: 50%
[D][light:058]:   Red: 50%, Green: 25%, Blue: 100%
[D][PlayerTV:343]: media_player.55_tcl_roku_tv Player source changed to YouTube
```

ralfkah, 2022-09-07:
Hell yeah, finally it's working. It seems that the tv I used in the TVSetup(...) call is not working reliably. I now changed it to another device and voila - the m5 is booting and showing me the menu!
Great!

I also reverted all changes you suggested in your first response. Even with the BootSequence-Call active again, the m5 is booting and working correctly.

Seems that it was my fault after all :-) Thanks for your help resolving it. Really appreciate it.

Ralf

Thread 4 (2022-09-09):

Great project. A few pointers/ideas.

jottr, 2022-09-09:
This is a great project @landonr.
I've been meaning to build a smart wall mounted "light switch" with Lilygo's [ESP32 Epaper display](https://www.aliexpress.com/item/1005002006058892.html).
I think the rotary encoder could be a good interface to navigate a simplified dashboard for homeassistant.

Sadly, drawing UX on these displays is not as straightforward as I initially hoped. The [EPDiy](https://github.com/vroland/epdiy) driver is a starting point, as is the [ESPUI](https://github.com/s00500/ESPUI) library.

I'm leaving this info here since I believe this might be interesting to others too.

landonr, 2022-09-09:
it seems like support for the Lilygo T5-4.7 is in progress for esphome which is all we need for support https://github.com/esphome/feature-requests/issues/1109#issuecomment-986018421

however im not sure if it would work well with the rotary because it needs the display to update as fast as possible. A d-pad might work better like https://github.com/adityapattiyeri/home-remote does

Closed 2022-11-07.

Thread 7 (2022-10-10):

More settings configurable

abroooo, 2022-10-10:
First of all kudos for this great project!
I've been tinkering with it for a couple of days (tdisplay with rotary wheel) and really am enjoying it especially the rotary wheel 😄

For my use I made the display and sleep timeouts configurable to be able to easily play with them. In my opinion having them hardcoded is not ideal since more users might want to change these values. What do you think?

Do you welcome PRs? I have limited time but would like to contribute to this project.

landonr, 2022-10-10:
glad you're liking the project, please share some pics!

PRs are welcome, feel free to add the settings to the globals and substitutions and make a pr. In the future it'd be nice to have some of these values adjustable in a menu on the remote

abroooo, 2022-10-10:
This is my prototype. Haven't had time to solder yet ...
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

landonr, 2022-10-10:
that's great! we're working on a case that just uses a cable which should be ready in the next few weeks

abroooo, 2022-10-10:
That sounds cool, can't wait to see it!

btw: your todo list mentions dimming of lights. Have you started on that yet? I just started to look into it. Just have to figure out how to get the current brightness and how exactly you structured the menus.

landonr, 2022-10-10:
I haven't started that, but if you want to take that on be my guest!

- we have `esphomeRemoteLight.h` which contains the state for the light. you can include the brightness right under `state_changed` and call it from setup
- you can add a `lightsDetailMenu` in `MenuStates` in `MenuGlobals.h` then fill out all the enums
- instead of selecting the light in `selectMenu()`, set the `activeMenuState` to `lightsDetailMenu`
- draw the menu you want in `drawMenu()`
- the rest of the menu code is in enums so it should give you compiler warnings until it's all set up
let me know how it goes

abroooo, 2022-10-11:
Thx for intro I'll look into it.

Menu logic wise I was thinking of _PressSelect_ to keep as is (on/off) and _PressRight_ to enter light details menu.

landonr, 2022-10-11:
that kind of breaks the ipod menu layout but I have no problem with it. maybe we could do hold select to toggle light and tap to enter menu?

landonr, 2022-10-11:
I want to keep select to always enter menus if possible (it shows a > arrow on the right of the title if theres a menu to enter). We should consider some lights can't do brightness / temperature (light switches) so some lights will only toggle.
So if we did select to enter lightDetail or toggle a light switch. Inside lightDetail we could have a slider for brightness which we could select to toggle quickly. That way it's 2 quick taps on a light with detail or just 1 on a switch

abroooo, 2022-10-11:
Alright, sounds good.

So then we want:
  * lightMenu:
    * tap light => enter lightDetail and show slider(s)
    * hold light => toggle light (<- do we need this?)
  * lightDetailMenu: (draw slider(s) on the screen)
    * tap light => toggle light
    * rotate => increase/decrease brightness

landonr, 2022-10-11:
hold light => toggle light. i was thinking this might be slower than tapping into the menu

#### lightDetailMenu: (draw slider(s) on the screen)
- how would it work if we had temperature and brightness?
- the lightDetail menu could be
    - light name (tap to toggle)
    - brightness (tap and scroll)
    - temperature (tap and scroll)
    - rgb color? (tap and scroll)

landonr, 2022-10-11:
by the way are you using Sonos? I'm curious how this works with other media player sources

abroooo, 2022-10-11:
> hold light => toggle light. i was thinking this might be slower than tapping into the menu

A bit slower probably

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

That's makes sense for me

>     - rgb color? (tap and scroll)

Hmm I can't imagine that this would be nice to control. We could have three sliders for the colors but for me personally this would be overkill 🙈

abroooo, 2022-10-11:
> by the way are you using Sonos? I'm curious how this works with other media player sources

Yes I'm using Sonos. Sources are empty for me and volume up/down doesn't have any effect. Haven't looked into it yet.
I only have one Sonos configured _media_player.<sonos_name>_ and also no TV. What provides the sources content in your video?

landonr, 2022-10-11:
> > by the way are you using Sonos? I'm curious how this works with other media player sources
>
> Yes I'm using Sonos. Sources are empty for me and volume up/down doesn't have any effect. Haven't looked into it yet. I only have one Sonos configured _media_player.<sonos_name>_ and also no TV. What provides the sources content in your video?

ill make a new issue for this

landonr, 2022-10-11:
> Hmm I can't imagine that this would be nice to control. We could have three sliders for the colors but for me personally this would be overkill 🙈

yeah I agree it's overkill but it's kinda cool. the color picker could be a hsv slider for rgb since brightness is separate. Like the top bar here

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

abroooo, 2022-10-12:
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

That would be a total _because we can feature_ and I like it 😆 !

landonr, 2022-10-12:
I think it looks good! It's pretty similar to the clock menu on ipod classic where there's double height rows. https://youtu.be/-USWx1WErMY?t=33

- We could put the light name in the header instead of Light Details
- We could make the brightness, and temperature double height and modify the menu code to support it
- Then you can just select either brightness, or temp and scroll to adjust, then select or menu to exit
- This double row height menu looks like it should be reusable if we implement sliders for curtains or hvac!

abroooo, 2022-10-12:
Thx! I really like your ideas. I think you meant something like this?::
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
How would we turn the light off/on? We need select to select one of the sliders. Press and hold doesn't seem very intuitive here.

There's a lot more to this feature then I initially thought 😆 The light detail menu is another layer added and it consists of a different type (sliders not strings) which also provide a different functionality. And we also need to remember the light selected for use in the light detail menu. Have you already thought about how you want the architecture to develop?

Maybe we could have a MenuItemBase class and derive MenuTitle and MenuSlider from it. That way we could use `drawMenu(std::vector<MenuTitle>)` for the new menu as well. Haven't thought this through yet though.

I'll think about it 😄

landonr, 2022-10-12:
- for remembering which light selected for detail we could do something like grouping where i just use this `speakerGroup -> newSpeakerGroupParent` to figure out which speaker you want set up. This doesn't seem very extendible because we'd need to set up a variable for each menu.
- maybe we keep a vector of the MenuTitles (or base menus) that we've entered as a `NavigationStack`. Then we can see what menu/entity we're in by looking at the top of the array, and it would allow us to pop the array to go back a page
- `MenuSlider` with the base is a good idea. It would need min, max, value, entityId, friendlyName, type (brightness, temp, rgb if we want to draw different slider types on screen)
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
landonr, 2022-10-13:
> - MenuSlider with the base is a good idea. It would need min, max, value, entityId, friendlyName, type (brightness, temp, rgb if we want to draw different slider types on screen)

>I think it'll be a bigger refactor and it probably makes sense to split this into multiple PRs?
how are we going to adjust the light values in this pr?

abroooo, 2022-10-13:
I'm not sure I get what you mean? Did you mean how are we going to get a functional light details menu without refactoring the menu?

I think something like this:
* we can save the currently selected light in `selectMenu()`
* probably have a function `drawMenuLightDetail()` which draws the new menu
* and then react in `selectMenu()` (set selection as well move the slider)
* when a slider is selected we also have to save that to react accordingly

What do you think? When a slider is selected and moved, where do we draw that?

landonr, 2022-10-13:
oh yeah I misunderstood, that sounds good for now!
> What do you think? When a slider is selected and moved, where do we draw that?

for volume there's a localVolumeLevel that updates the volume level of a speaker. the local volume level is kept for the ui because it takes a while for home assistant to reply with the updated state. we can do the same thing for the slider value in lights by keeping a local brightness value and subscribing to the brightness

abroooo, 2022-10-14:
Alright, I got it working. I implemented it like this:

* `ButtonPressNext` and `ButtonPressPrevious` for scrolling the menu
* `ButtonPressSelect` to select either toggle the light or select one of the sliders
* if slider is selected `ButtonPressNext` and `ButtonPressPrevious` to increase/decrease  color temperature / brightness
* if slider is selected `ButtonPressUp` to deselect

Whats left to do:
* draw animated sliders
* draw selection
* tidy up

There's some hard-coded stuff (couldn't use MenuTitle class for the items). When I send the PR we should discuss if we want to leave this for now and do that when we refactor the menu or do it right now.

abroooo, 2022-10-14:
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

Good to know. I currently have the brightness/color_temp as a class member and increase/decrease it when changing the brightness/color_temp. It's also updated by the callback from the subscription (pretty much as you suggested in your comment). I'm not sure if this can be a problem in terms of data consistency.

I experienced some problems when updating birghtness/color_temp. After a number of successive changes the light got unresponsive. Not sure if it's the light/zigbee network/something else. Just thought I'd mention it because maybe you already know/experienced this and ideally have an idea 😛 If not I'll add to my list of _stuff to look up/find out_ and it would/should be a known limitation because there's nothing we can do from the code.

landonr, 2022-10-14:
it might stop responding if you spam too many calls to the light.. Maybe we should make it only update the light after selecting on the slider for now instead of on scroll to see if it fixes it?

abroooo, 2022-10-17:
> it might stop responding if you spam too many calls to the light.. Maybe we should make it only update the light after selecting on the slider for now instead of on scroll to see if it fixes it?

I'd like to keep the instantly-changing style because that feels better than selecting a brightness and then setting it. If it leads to problems for some users we could make it optional? Or maybe a customizable rate limit?

abroooo, 2022-10-31:
> that's great! we're working on a case that just uses a cable which should be ready in the next few weeks

I'm curious, how's it going?

landonr, 2022-10-31:
> > that's great! we're working on a case that just uses a cable which should be ready in the next few weeks
>
> I'm curious, how's it going?

i'll follow up on discord

landonr, 2022-11-09:
@abroooo here's a pic of the case so far
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

the rotary, battery and tdisplay mount to the case so we wont need a circuit board, only a cable to connect the rotary. the idea is to keep the price really cheap for this version. once we finish this off it would be fun to make a custom pcb with a different screen and more buttons

theres more pics on discord, i fixed the invite link https://discord.gg/BX6ZtGKHTy

abroooo, 2022-11-10:
@landonr that looks awesome 👊🏻🚀 and also nice that no extra pcb is needed. That makes it more accessible I think.

Will you add the files for the case to the repo?

landonr, 2022-11-17:
we'll add them as soon as we can

Closed 2022-11-17.

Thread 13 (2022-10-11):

Sonos Favorites aren't loaded

landonr, 2022-10-11:
**Describe the bug**
Sonos favorites are empty because they rely on a home assistant template

**Expected behavior**
All the sonos favorites should be listed in the Sources menu

**Additional context**
I use this template to get favorites formatted for the device but it should load the existing sensor.sonos_favorites
```
      - name: Sonos Favorites List
        state: 'OK'
        attributes:
          items: '{{ state_attr("sensor.sonos_favorites", "items").values() | list | join("~") }}'
```

abroooo, 2022-10-12:
Oh nice, the workaround did the trick for me 👍
I don't mind the extra sensor but you're right, it's an external dependency.

landonr, 2022-10-12:
If we can get rid of the sensor, we should be able to load playlists from spotify too. Spotcast has this playlists sensors that returns the same as the default sonos sensor
```
playlists:
- uri: spotify:playlist:37i9dQZF1EIdNK9vIbNBMb
  name: Morning Mix
- uri: spotify:playlist:4772bP5KCO80HXMQsr7aol
  name: S/S 22 🫶🏻
...
```

landonr, 2022-10-14:
https://github.com/landonr/esphome-remote/pull/14

landonr, 2022-10-15:
just need to add docs

abroooo, 2022-10-17:
yeees 😄

abroooo, 2022-10-19:
docs look fine. I'm nevertheless struggling to get it working but that has nothing to do with your docs. I have a `sensor.playlists_sensor` but it does only contain a few of my playlists. I can see these in the Sources menu on my remote so that's working fine 😄
Good job 👍

Closed 2022-10-20.

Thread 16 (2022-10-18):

remote wont boot without media players configured

goxofy, 2022-10-18:
Is it possible to support this hardware?

LILYGO® TTGO T-Display Keyboard For LNURLPoS

https://m.tb.cn/h.UeTxbek?tk=sYnC2zqligT

thanks a lot!

landonr, 2022-10-18:
Yes it would be very easy to set up. The code for the rotary is 5 buttons (up,down,left,right,select) and 2 rotary directions (left,right). This keypad has 12 buttons + so you can easily just call the existing functions from the keypad buttons

goxofy, 2022-10-19:
Hi @landonr , i am not a programer, could you please tell me which src file should I change? thanks!

landonr, 2022-10-19:
what do you want each button to do?

landonr, 2022-10-20:
here's the functions you have to call for each button
```
5 - buttonPressSelect();
4- buttonPressLeft();
6 - buttonPressRight();
8 - buttonPressDown();
2 - buttonPressUp();

# - buttonPressNext();
* - buttonPressPrevious();
```
in order to actually set up that keypad this component might be helpful https://github.com/Syralist/esphomekeypad. You can include that and then call the appropriate function based on which number is pressed

goxofy, 2022-10-20:
@landonr ok thanks, i'll try this

landonr, 2022-10-20:
just noticed this component which is better supported should be more straightforward to set up https://github.com/ssieb/custom_components/tree/vbus/components/matrix_keypad

goxofy, 2022-10-21:
OK，thanks!

goxofy, 2022-10-31:
hi @landonr , I have a question about tdisplay with Scrollwheel, what the Scrollwheel's enca pin and encb pin connect to?

landonr, 2022-10-31:
I have it set up on pin 12 and 13. that side has enough IO for all of the buttons and the encoder. here's the esphome setup
```
sensor:
## Rotary
  - platform: rotary_encoder
    filters:
    - throttle: 0.01s
    name: "Rotary Encoder"
    internal: true
    pin_a:
      number: 12
      mode:
        input: true
        pullup: true
    pin_b:
      number: 13
      mode:
        input: true
        pullup: true
    id: rotary
    on_clockwise:
      - lambda: |-
          buttonPressWakeUpDisplay();
          buttonPressNext();
    on_anticlockwise:
      - lambda: |-
          buttonPressWakeUpDisplay();
          buttonPressPrevious();
```

goxofy, 2022-11-01:
hi @landonr

I made this remote with scrollwheel but when I power on the tdisplay, it only shows a logo, it doesn't work when i press any key.

the logs here, please help me

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

landonr, 2022-11-01:
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

Have you set up the device in home assistant?

goxofy, 2022-11-01:
yes， I set up it in home assistant

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

landonr, 2022-11-02:
have you configured the media players in the `sharedRemoteConfig.yaml` to match your setup? It will show the boot screen until it finds a media player so the UI doesn't have empty states

goxofy, 2022-11-03:
Hi @landonr , thanks for your reply!

I dont have a media player, I just want to control my lights and scene and scripts in home assistant ,so I deleted some code in the `sharedRemoteConfig.yaml`, here is my yaml , is it right?

```
logger:
  level: INFO

api:
  services:
    - service: goto_screen
      variables:
        screen_name: string
      then:
      - lambda: |-
          goToScreenFromString(screen_name);

ota:

wifi:
  ssid: ${wifi_ssid}
  password: ${wifi_password}
  fast_connect: true

  ap:
    ssid: "${friendly_name} Fallback"
    password: ${wifi_fallback_password}

captive_portal:

http_request:
  useragent: esphome/device
  timeout: 10s

color:
  - id: my_red
    red: 100%
    green: 0%
    blue: 0%
  - id: my_yellow
    red: 100%
    green: 75%
    blue: 10%
  - id: my_green
    red: 0%
    green: 100%
    blue: 0%
  - id: color_accent_primary
    red: ${color_accent_primary_red}
    green: ${color_accent_primary_green}
    blue: ${color_accent_primary_blue}
  - id: my_gray_dark
    red: 40%
    green: 40%
    blue: 40%
  - id: my_gray_dark_2
    red: 8%
    green: 8%
    blue: 8%
  - id: my_gray
    red: 10%
    green: 10%
    blue: 10%
  - id: my_black
    red: 0%
    green: 0%
    blue: 0%
  - id: my_white
    red: 100%
    green: 100%
    blue: 100%

font:
## Font needs to be monospace!
  - file: "fonts/iosevka.ttf"
    id: large_font
    size: ${large_font_size}
    glyphs: '*/\$#<>!?"%()[]+=,-_.:°0123456789ABCDEFGHIJKLMNOPQRSTUVWXYZ abcdefghijklmnopqrstuvwxyz&êÊîÎâÂôÔéÉíÍáÁóÓëËüÜïÏṣṢ''’'
  - file: "fonts/iosevka.ttf"
    id: medium_font
    size: ${medium_font_size}
    glyphs: '*/\$#<>!?"%()[]+=,-_.:°0123456789ABCDEFGHIJKLMNOPQRSTUVWXYZ abcdefghijklmnopqrstuvwxyz&êÊîÎâÂôÔéÉíÍáÁóÓëËüÜïÏṣṢ''’'
  - file: "fonts/iosevka.ttf"
    id: small_font
    size: ${small_font_size}
    glyphs: '*/\$#<>!?"%()[]+=,-_.:°0123456789ABCDEFGHIJKLMNOPQRSTUVWXYZ abcdefghijklmnopqrstuvwxyz&êÊîÎâÂôÔéÉíÍáÁóÓëËüÜïÏṣṢ''’'
  - file: 'fonts/materialdesignicons-webfont.ttf'
    id: material_font_large
    size: ${icon_size_large}
    glyphs: [
      '󰐊', # mdi-play
      '󰓛', # mdi-stop
      '󰏤', # home-pause
      '󰽥', # mdi-moon-waning-crescent
      '󰒝', # mdi-shuffle
      '󰒞', # mdi-shuffle-disabled
      '󰕾', # mdi-volume-high
      '󰕿', # mdi-volume-low
      '󰚺', # mdi-plex
      '󰝆', # mdi-netflix
      '󰗃', # mdi-youtube
      '󰓇', # mdi-spotify
      '󰔂', # mdi-television
    ]
  - file: 'fonts/materialdesignicons-webfont.ttf'
    id: material_font_small
    size: ${icon_size}
    glyphs: [
      '󰐊', # mdi-play
      '󰓛', # mdi-stop
      '󰏤', # home-pause
      '󰽥', # mdi-moon-waning-crescent
      '󰒝', # mdi-shuffle
      '󰒞', # mdi-shuffle-disabled
      '󰕾', # mdi-volume-high
      '󰕿', # mdi-volume-low
      '󰚺', # mdi-plex
      '󰝆', # mdi-netflix
      '󰗃', # mdi-youtube
      '󰓇', # mdi-spotify
      '󰔂', # mdi-television
    ]

globals:
## Size of the large font above
  - id: large_font_size
    type: int
    restore_value: no
    initial_value: ${large_font_size}

## Size of the medium font above
  - id: medium_font_size
    type: int
    restore_value: no
    initial_value: ${medium_font_size}

## Size of the small font above
  - id: small_font_size
    type: int
    restore_value: no
    initial_value: ${small_font_size}

## Height / width ratio of the monospace font used
  - id: font_size_width_ratio
    type: double
    restore_value: no
    initial_value: "0.6"

## Status bar height
  - id: header_height
    type: int
    restore_value: no
    initial_value: ${header_height}

## Global margin size
  - id: margin_size
    type: int
    restore_value: no
    initial_value: ${margin_size}

## Scrollbar total width
  - id: scroll_bar_width
    type: int
    restore_value: no
    initial_value: ${scroll_bar_width}

## Volume bar and media duration bar margin
  - id: bottom_bar_margin
    type: int
    restore_value: no
    initial_value: ${bottom_bar_margin}

## Height and width of the icons used in px
  - id: icon_size
    type: int
    restore_value: no
    initial_value: ${icon_size}

## Height and width of the icons used in px
  - id: icon_size_large
    type: int
    restore_value: no
    initial_value: ${icon_size_large}

## Max lines on now playing screen before truncating happens
  - id: now_playing_max_lines
    type: int
    restore_value: no
    initial_value: ${now_playing_max_lines}

## Draw buttons in now playing menu for 3 button devices
  - id: draw_now_playing_menu
    type: bool
    restore_value: no
    initial_value: ${draw_now_playing_menu}

## Draw battery icon if battery level is supported
  - id: draw_battery_level
    type: bool
    restore_value: no
    initial_value: ${draw_battery_level}

## Draw volume level in header
  - id: draw_volume_level
    type: bool
    restore_value: no
    initial_value: ${draw_volume_level}

## Draw shuffle icon if shuffle is disabled
  - id: draw_shuffle_disabled
    type: bool
    restore_value: no
    initial_value: ${draw_shuffle_disabled}

## Draw time in header
  - id: draw_header_time
    type: bool
    restore_value: no
    initial_value: ${draw_header_time}

## Customize device boot name
  - id: boot_device_name
    type: std::string
    restore_value: no
    initial_value: ${boot_name}

## Turn off display after x seconds of idle
  - id: display_timeout
    type: int
    restore_value: no
    initial_value: ${display_timeout}

## Go to sleep after x seconds of idle
  - id: sleep_after
    type: int
    restore_value: no
    initial_value: ${sleep_after}

## Let the menu selection roll-over when reaching the beginning/end
  - id: menu_rollover_on
    type: bool
    restore_value: no
    initial_value: ${menu_rollover_on}

## Find a new active media player if the current active one stops playing
  - id: sync_active_player
    type: bool
    restore_value: no
    initial_value: ${sync_active_player}

## Black background
  - id: dark_mode
    type: bool
    restore_value: no
    initial_value: ${dark_mode}

interval:
  - interval: 1s
    then:
    - lambda: |-
        idleTick();
  - interval: 0.3s
    then:
    - lambda: |-
        activeTick();

deep_sleep:
  id: deep_sleep_1

binary_sensor:
  - platform: status
    name: "${boot_name} Node Status"
    id: system_status

time:
  - platform: homeassistant
    id: esptime

custom_component:
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
goxofy, 2022-11-03:
Does it I must use a battery?

landonr, 2022-11-04:
thanks for the config! I haven't considered using the remote without media player stuff so I'll try to get it working tonight.
no battery isn't required. you can hide the battery level with the draw_battery_level. you need to keep the battery_percent sensor but it can be whatever value.
by the way being able to call the elevator is so cool!

goxofy, 2022-11-04:
Hi @landonr ，I tried to connect a battery and now it works!!

I am waiting for your pr and maybe I could pull a request to support the switches in HA?

Call elevator:

https://user-images.githubusercontent.com/1695416/199864543-cc822276-efb9-49f4-9de3-5a75423934c2.mp4

goxofy, 2022-11-04:
The device is unstable , I must reboot devices for  many times then it will be enter main menu, here is some logs

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

landonr, 2022-11-04:
ill check it out after work sorry I didn't get to this last night. cool elevator video I wish i could figure out how to get my elevator to get called from an api!

landonr, 2022-11-05:
can you rename this issue to something like 'remote wont boot without media players configured'. I made this PR to get started on this https://github.com/landonr/esphome-remote/pull/19

I'll look at the battery issue in a bit

goxofy, 2022-11-05:
ok of course!

landonr, 2022-11-05:
> Hi @landonr ，I tried to connect a battery and now it works!!
>
> I am waiting for your pr and maybe I could pull a request to support the switches in HA?

absolutely if you want to help out! it should be pretty similar to the basic light component in esphomeRemoteLight.h

I think you can also work around this by just setting up your switch as a basic light in the config

goxofy, 2022-11-06:
Hi @landonr , I tried to support the switches but failed.. I am not a programmer.:)

goxofy, 2022-11-07:
Hi @landonr , I made  a breakout PCB for tdisplay and scroolwheel,like this

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

landonr, 2022-11-07:
@goxofy that's awesome! I'm going to make a new issue for the breakout PCB so we can close this up

landonr, 2022-11-07:
> Hi @landonr , I tried to support the switches but failed.. I am not a programmer.:)

no worries! I'll make an issue for this and work on it when I have time

Closed 2022-11-07.

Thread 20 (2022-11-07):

Cool Project! Could it support Chinese? Thanks

sylvia69999, 2022-11-07:
If I want to use chinese on my remote, what shoud I do?

Thanks

landonr, 2022-11-07:
yes you should be able to replace the characters here with the ones you're using and then build the project. Let me know how it goes https://github.com/landonr/esphome-remote/blob/main/esphomeRemote/sharedRemoteConfig.yaml#L73

sylvia69999, 2022-11-09:
```
  - file: "fonts/font.ttf"
    id: large_font
    size: ${large_font_size}
    glyphs: '儿童房台灯*/\$#<>!?"%()[]+=,-_.:°0123456789ABCDEFGHIJKLMNOPQRSTUVWXYZ abcdefghijklmnopqrstuvwxyz&êÊîÎâÂôÔéÉíÍáÁóÓëËüÜïÏṣṢ''’'
  - file: "fonts/font.ttf"
    id: medium_font
    size: ${medium_font_size}
    glyphs: '儿童房台灯*/\$#<>!?"%()[]+=,-_.:°0123456789ABCDEFGHIJKLMNOPQRSTUVWXYZ abcdefghijklmnopqrstuvwxyz&êÊîÎâÂôÔéÉíÍáÁóÓëËüÜïÏṣṢ''’'
  - file: "fonts/font.ttf"
    id: small_font
    size: ${small_font_size}
    glyphs: '儿童房台灯*/\$#<>!?"%()[]+=,-_.:°0123456789ABCDEFGHIJKLMNOPQRSTUVWXYZ abcdefghijklmnopqrstuvwxyz&êÊîÎâÂôÔéÉíÍáÁóÓëËüÜïÏṣṢ''’'
```

```
FriendlyNameEntity("light.ertongfang", "儿童房台灯"),
```

sylvia69999, 2022-11-09:
sorry, I don't know how to upload the TTF file.

landonr, 2023-09-12:
this should be easy now that gfonts and online fonts can be downloaded on build

Closed 2023-09-12.

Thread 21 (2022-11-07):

Breakout PCB for tdisplay and scrollwheel

landonr, 2022-11-07:
Hi @landonr , I made  a breakout PCB for tdisplay and scroolwheel,like this

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

_Originally posted by @goxofy in https://github.com/landonr/esphome-remote/issues/16#issuecomment-1304970234_

landonr, 2022-11-07:
@goxofy first off this is awesome work, thank you!

How would we connect the battery to the tdisplay? I think we can add a pin on the back of the pcb for vin/ground and include a battery header

goxofy, 2022-11-14:
I am designing a power mnagement IC for the board in order to charge by the typec on ESP.

landonr, 2022-11-14:
the tdisplay includes a power manager ic. are you sticking with the tdisplay?

goxofy, 2022-11-14:
i am trying to change the builtin ic, now the battery charing is inconvenient

landonr, 2022-11-14:
ah that makes sense. The tdisplay screen is really small. would it make sense to upgrade to a standalone display that's larger like a ILI9341 and use a different esp32 chip?

goxofy, 2022-11-15:
Or can we add another power ic on the board to charge the battery standalone?

landonr, 2022-11-15:
which ic are you looking at? it would be nice to have one with an accurate fuel guage

goxofy, 2022-11-15:
I bought this https://detail.tmall.com/item.htm?id=677456511513&spm=a1z09.2.0.0.4c4f2e8dfx6BFo&_u=f49o7j09dd1 still on the way

landonr, 2022-11-15:
I cant see that without signing up and I don't understand the language. Can you share a screenshot of the specs?

landonr, 2023-03-27:
@goxofy can you share the pcb

Closed 2023-10-22.

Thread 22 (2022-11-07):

Support Home Assistant switches

landonr, 2022-11-07:
Hi @landonr , I tried to support the switches but failed.. I am not a programmer.:)

_Originally posted by @goxofy in https://github.com/landonr/esphome-remote/issues/16#issuecomment-1304818064_

we should add support for on/off switches in home assistant

Closed 2022-11-15.

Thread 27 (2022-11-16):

Volume adjustment not working with music assistant

landonr, 2022-11-16:
**Describe the bug**
The volume isn't updating on music assistant https://github.com/music-assistant/hass-music-assistant

**To Reproduce**
Steps to reproduce the behavior:
1. pair a music assistant speaker to the device
2. adjust volume

**Additional context**
I think we're sending "entityIds" instead of "entityId" for the service call so it isn't being accepted

landonr, 2023-09-12:
tested an it's working

Closed 2023-09-12.

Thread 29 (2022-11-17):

3d printed case

landonr, 2022-11-17:
**Is your feature request related to a problem? Please describe.**
the bare components are too pokey

**Describe the solution you'd like**
a 3d printed case where the components are mounted by screws. The case could have pogo pins to charge easily.

**Describe alternatives you've considered**
we've considered building the case around a PCB but since the components are basic we can skip that and wire everything together using jumper cables

**Additional context**
requirements
- fits tdisplay
- fits a lipo
- fits ano rotary controller
- doesn't melt while charging
- passthrough buttons for tdisplays internal buttons
- usbc port hole

landonr, 2022-11-17:
here's two different concepts from Jasper who posted in Discord

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

abroooo, 2022-11-18:
Great job in designing these case 🎉
I personally would love to have something small (maybe think of ipod nano or just your protoype with a case around it). Then maybe we don't need pogo pins and just break out the onboard usbc port out?

landonr, 2022-11-18:
this case is designed around a 2200mah lipo so it's about as small as it could be. I don't think the pogo pins are mandatory so we could make a version with or without at this same size

JasperCohen, 2022-11-18:
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

This isn't the final case but i think i will be moving forward with some of the aesthetic features, like the front profile and the back shape. I'm still massaging the screen, and the front surface.

JasperCohen, 2022-11-18:
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
Also, i know its weird placement but i think this could be a decent spot for a pogo connector. I say this because its dead space right now.

landonr, 2022-11-19:
That looks so good! have you tried printing any prototypes yet? I think for the pogo pin we'd need to make a dock so we can put the pogo pin wherever it works

abroooo, 2022-11-19:
> this case is designed around a 2200mah lipo so it's about as small as it could be. I don't think the pogo pins are mandatory so we could make a version with or without at this same size

ahh I see, also can see it on @JasperCohen cross section drawing. And seeing the pictures with transparent case it doesn't look that big at all 😄  Great work @JasperCohen 🚀

JasperCohen, 2022-11-20:
@landonr this is really just the surfacing so the case isn't ready for printing yet, but at this point I'm going to move ahead with this design with only minor tweaks to the screen trim.

my goal is to get a printable solid design by today!

landonr, 2022-11-21:
@JasperCohen thanks for adding the reverse engineered parts #32 and for sharing this on discord!
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
this looks super professional take your time!

landonr, 2023-05-01:
case is ordered from our new sponsor, PCBWay!
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

Closed 2023-05-01.

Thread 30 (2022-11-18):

Graphs for sensors

abroooo, 2022-11-18:
**Is your feature request related to a problem? Please describe.**
Sensors currently only show numeric values.

**Describe the solution you'd like**
By pressing the sensor menu item it could show a graph over the last x min/hours

**Describe alternatives you've considered**
Instead of drawing it could be a solution to receive a png (from HA) and display that. I wouldn't prefer showing pngs because it would require external configuration and I'm not sure it's possible with our device.

**Additional context**
I investigated a bit and it;s it pretty doable to show a graph. The tricky part is getting the data to show. Natively esphome only supports collecting values over a period of time and show them in a graph. But I would like to see a graph for a sensor even if I just turned on the remote (or return it from deep sleep). Maybe this could be resolved by having ha send an array of values on demand but it would mean external configuration. AFAIK ha doesn't support that natively.

abroooo, 2022-11-19:
Oh the ha rest api, nice idea - havent thought of set to be honest.
I don't think we need to implement our own graph. `esphome::display::DisplayBuffer::graph()` takes a pointer to an `esphome::graph::Graph` object. We can build this object ourselves.

landonr, 2022-11-22:
are you using a long lived access token? https://developers.home-assistant.io/docs/auth_api/#making-authenticated-requests

abroooo, 2022-11-22:
Yes I am

abroooo, 2022-11-23:
After poking through the esphome code to no avail I found the error - it was the token 🤦‍♂️  I somehow missed a character. After fixing the token it works fine....

landonr, 2022-11-24:
nice! pics

abroooo, 2022-11-25:
yeah I'm pretty much at the beginning so there aren't any pics yet - sorry 😞

I think I'll approach it like this:

- parse json into array
- build `esphome::graph::HistoryData` object
- build `esphome::graph::GraphTrace` object
- build `esphome::graph::Graph` object
- show `esphome::graph::Graph` obect via `esphome::display::DisplayBuffer:Graph`

landonr, 2023-01-24:
this is really interesting
https://github.com/esphome/esphome/pull/3255#issuecomment-1397300681
this person loads a graph as a png created from https://weewx.com/
I think loading the json from history and drawing the graph on the device is the right move, but this is an interesting approach/hack

abroooo, 2023-01-26:
oh yeah that's nice indeed. I agree, pulling the data from HA and visualizing it on device is the way to go.
btw. it will take me some more time as life keeps me pretty busy atm 😐

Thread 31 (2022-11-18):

Kodi navigation

abroooo, 2022-11-18:
**Is your feature request related to a problem? Please describe.**
Support kodi navigation

**Describe the solution you'd like**
We could have a mode which sends all commands to kodi (`rotate left` => `menu down`) to be able to have a basic navigation through kodi.

**Describe alternatives you've considered**
-

**Additional context**
Possible features:
- up/down/left/right
- play/pause/stop
- volume up/down
I think this would only make sense for devices which have a scroll wheel

landonr, 2022-11-18:
nice idea! I'll try to install Kodi and get this working while I do the LG webOS stuff

abroooo, 2022-11-19:
Awesome!

landonr, 2023-04-02:
#41

Closed 2023-04-02.

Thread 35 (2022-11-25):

RGB Lights

landonr, 2022-11-25:
**Is your feature request related to a problem? Please describe.**
change color of rgb lights

**Describe the solution you'd like**
rgb hsv slider

landonr, 2022-11-25:
@abroooo what do you think about this for a change to the light detail menu? It shows the light name in the header and the toggle (shows On) previews the light's color
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

abroooo, 2022-11-25:
@landonr I'm not sure I understand correctly. IIUC the light in your image is in color mode. If it is in color mode than I think we don't need to show the color temperature slider because it has no effect in this mode. When in color mode we could have something like this maybe?:

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
But I like having the title in the header and the toggle just saying on/off.

The color slider would behave like the other sliders. Then we wouldn't need to show a color preview in the toggle.

How would we switch between color mode and color temp mode?
We could:

- have another toggle for switching the modes (I'm not really into that idea)
- use buttonPressDown when color slider selection is active to toggle modes
- something else?

landonr, 2022-11-25:
- yeah I think I see what you're saying. there's no way to even show a color slider preview if the light is in temp mode (and visa versa).
- I like the idea of showing a preview of the light because it seems fun to code (and I think the base lights menu would look cool if all the toggles had color previews)
- what if the on was an option select (with `off`, `color`, `temp` as the options) similar to tempo in this gem menu 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

btw is there a way to contact you more directly? could you join the discord or email me (in my profile). I would have just messaged you about this instead of making an issue if i had the option

abroooo, 2022-11-25:
> * yeah I think I see what you're saying. there's no way to even show a color slider preview if the light is in temp mode (and visa versa).

exactly

> * I like the idea of showing a preview of the light because it seems fun to code (and I think the base lights menu would look cool if all the toggles had color previews)

yeah I made a prototype and it was indeed fun. If we do it like in my picture above we'll have two-hundred-something colors which I guess are enough? If not we would need to scroll the color bar or sth.

> * what if the on was an option select (with `off`, `color`, `temp` as the options) similar to tempo in this gem menu 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

I thought about that as well and I think I wouldn't do that because the light would probably flicker or change color when you just want to switch it off. You know what I mean?

>
> btw is there a way to contact you more directly? could you join the discord or email me (in my profile). I would have just messaged you about this instead of making an issue if i had the option

I send you a message 😄

landonr, 2022-11-25:
> yeah I made a prototype and it was indeed fun. If we do it like in my picture above we'll have two-hundred-something colors which I guess are enough? If not we would need to scroll the color bar or sth.

we wouldn't have to code all of the colors. the slider position is 0-360 and we can do hsv to rgb conversion. brightness would be the "value" and slider is the hue. saturation is always 100%. https://www.rapidtables.com/convert/color/hsv-to-rgb.html

> I thought about that as well and I think I wouldn't do that because the light would probably flicker or change color when you just want to switch it off. You know what I mean?

we could make it so it wouldnt set the state until you hit center again. so if its on itd be `select` -> `scroll up to "off` -> `select` to confirm

abroooo, 2022-11-29:
> > yeah I made a prototype and it was indeed fun. If we do it like in my picture above we'll have two-hundred-something colors which I guess are enough? If not we would need to scroll the color bar or sth.
>
> we wouldn't have to code all of the colors. the slider position is 0-360 and we can do hsv to rgb conversion. brightness would be the "value" and slider is the hue. saturation is always 100%. https://www.rapidtables.com/convert/color/hsv-to-rgb.html

oh that's nice, I didn't know that!
Would that be feasible for the user? Because you can to know how hsv works in order to adjust the light to the desired color. In HA you just have a scroll wheel.

The RGB slider would be easy to code as well but not as easy as the hsv stuff.

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

Hmm I think from a users perspective I wouldn't like that because there are extra actions required when I just want to turn off the light. Or did I get it wrong?

landonr, 2022-11-30:
`Hmm I think from a users perspective I wouldn't like that because there are extra actions required when I just want to turn off the light. Or did I get it wrong?`
yeah youre right. What if center always toggled the light, and the option button (under the usb) entered the light detail menu? We could add a different icon to the right of the row to indicate there's an option menu to enter.
or tapping and holding on one of the rows?

landonr, 2022-12-01:
for the selector this is what i'm thinking. still need to figure out how to toggle the light as easily a regular light
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

Closed 2023-01-09.

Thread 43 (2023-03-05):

add custom commands to option menu

landonr, 2023-03-05:
when youre in the now playing menu and you hit the option menu, there are preset options

tv:
 - remote menu
 - tv power
 - back
 - home
 - pause

speaker:
- shuffle
- mute
- group

we should add custom commands in here so people can do stuff like mute for 30s, toggle a scene, etc

landonr, 2023-05-01:
also add start playlist from song

landonr, 2023-07-19:
fixed in #64

Closed 2023-07-19.

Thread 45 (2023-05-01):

m5stack - option menu is broken

landonr, 2023-05-01:
**Describe the bug**
it says "SHUFFLE" for every item and you cant navigate

**To Reproduce**
Steps to reproduce the behavior:
1. Go to now playing
4. See error

**Expected behavior**
it should show the option menu items and let you scroll horizontally with the side buttons

**Additional context**
also an issue on tdisplay t4

landonr, 2023-05-04:
fixed in #47

Closed 2023-05-04.

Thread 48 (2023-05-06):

add unlock function

landonr, 2023-05-06:
**Is your feature request related to a problem? Please describe.**
the remote changes song while in my pocket

**Describe the solution you'd like**
scroll to unlock

**Describe alternatives you've considered**
press button sequence to unlock

**Additional context**
lock screen when it fades out
add option to disable lock
look into adding a switch for locking

Closed 2023-05-16.

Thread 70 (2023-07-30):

Lilygo T-Display-S3 Example Config Broken - Touch screen doesn't operate menu

sammcj, 2023-07-30:
**Describe the bug**

Howdy, I have a T-Display-S3 - homeThing installs fine and boots, but the menu doesn't respond to the touch screen.

Additionally by default the two physical buttons do not seem to do any other than wake the screen, I'm pretty sure this is just a matter of GPIO mappings which I'll fix - but perhaps the example config is broken here too.

The touch screen itself is working as I can see in the logs it's correctly registering touches.

**To Reproduce**
Steps to reproduce the behaviour:
1. Install homeThing on T-Display-S3 using example config.
2. Upon boot try using the menu.

**Expected behaviour**

To be able to navigate the menu on the touch screen by touching the items and/or using directional swiping gestures.

**Screenshots**
N/A

**Desktop (please complete the following information):**
 - OS: homeThing
 - Browser N/A?
 - Version 0.0.6

**Smartphone (please complete the following information):**

Don't see how this is relevant.

**Additional context**

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

Config file as follows.

```yaml
esphome:
  name: esp-s3
  platformio_options:
    board_build.f_flash: 80000000L
    board_upload.flash_size: 16MB
    board_build.partitions: default_16MB.csv
    board_build.arduino.memory_type: qio_opi

esp32:
  board: esp32-s3-devkitc-1
  variant: esp32s3
  framework:
    type: arduino

# Enable logging
logger:

# Enable Home Assistant API
api:

ota:
  password: !secret ota

wifi:
  ssid: !secret wifi_ssid
  password: !secret wifi_password

  # Enable fallback hotspot (captive portal) in case wifi connection fails
  ap:
    ssid: "S3 Fallback Hotspot"
    password: "zQ9tuPKIfFMu"

time:
  - platform: homeassistant
    id: ha_time

binary_sensor:
  - platform: gpio
    pin:
      number: GPIO0
      inverted: true
    name: "Button 1"
  - platform: gpio
    pin:
      number: GPIO14
      inverted: true
    name: "Button 2"

i2c:
  scl: 17
  sda: 18

font:
  - file: "gfonts://Roboto"
    id: roboto
    size: 30

display:
  - platform: tdisplays3
    id: my_display
    rotation: 90
    update_interval: 10s
    lambda: |-
      id(homeThingMenu)->draw_menu_screen();
      return;

touchscreen:
  - platform: tdisplays3
    interrupt_pin: 16
    address: 0x15
    x_offset: 40
    id: my_touchscreen
    on_touch:
      - lambda: |-
          ESP_LOGI("tdisplays3-touch", "x:%d, y:%d",
            id(my_touchscreen).x,
            id(my_touchscreen).y
          );

external_components:
  - source: github://landonr/lilygo-tdisplays3-esphome
    components: [tdisplays3]
    refresh: 0s
  - source: github://landonr/homeThing
    refresh: 0s
    components: [homeThing] # homething menu
  - source: github://landonr/esphome-components
    refresh: 0s

packages:
  remote_package:
    url: https://github.com/landonr/homeThing
    ref: main
    files: [
        common/device_base.yaml, # defines api, ota, free memory and uptime sensor
        common/ipod/lilygo_tdisplay_ipod_battery.yaml, # used for battery percent
        common/ipod/lilygo_tdisplay_ipod_binary_sensor.yaml, # used for button controls
        common/ipod/lilygo_tdisplay_ipod_rotary.yaml, # used for rotary controls
        common/ipod/lilygo_tdisplay_ipod_sleep.yaml, # required for device to sleep
        common/tdisplay-s3/backlight.yaml, # backlight
        common/fonts.yaml, # default font
        common/icon_fonts.yaml, # material icons
        common/settings.yaml, # settings screen
      ]
    refresh: 0s

substitutions:
  friendly_name: "s3 homething"
  rotary_left_pin: "2"
  rotary_right_pin: "10"
  rotary_up_pin: "3"
  rotary_down_pin: "1"
  rotary_select_pin: "11"
  rotary_pin_a: "13"
  rotary_pin_b: "12"
  screen_left_pin: "GPIO0"
  screen_right_pin: "GPIO14"
  battery_pin: "4"

color: # setup primary accent colour
  - id: my_primary_accent
    red_int: 75
    green_int: 45
    blue_int: 209

light:
  # backlight
  - platform: monochromatic
    output: gpio38
    name: "Backlight"
    restore_mode: RESTORE_DEFAULT_ON
  # home assistant lights
  - platform: homeassistant_component
    id: light_livingroom
    entity_id: light.livingroom
    name: Livingroom Light Group
  - platform: homeassistant_component
    id: light_study
    entity_id: light.study
    name: Study Light Group
  - platform: homeassistant_component
    id: light_bedroom
    entity_id: light.bedroom
    name: All Lights

homeThing:
  id: homeThingMenu
  settings:
    sleep_after: 14400
  sleep_switch: sleep_toggle
  backlight: backlight
  battery:
    battery_percent: battery_percent
    charging: charging
  # media_player_group: media_group_component
  display: my_display
  on_redraw:
    then:
      component.update: my_display
  display_state:
    colors:
      accent_primary: my_primary_accent
    draw_battery_level: true
    font_small: small_font
    font_medium: medium_font
    font_large: large_font
    font_large_heavy: large_heavy_font
    font_material_large: material_font_large
    font_material_small: material_font_small
    font_logo: home_thing_logo
  screens:
    - name: Lights Screen
      entities:
        - id: light_livingroom
          type: light
        - id: light_study
          type: light
        - id: light_bedroom
          type: light

        - type: command
          name: "bedroom lights"
          command:
            - homeassistant.service:
                service: light.toggle
        - type: command
          name: "lights off"
          command:
            - homeassistant.service:
                service: light.turn_off
        - type: command
          name: "lights on"
          command:
            - homeassistant.service:
                service: light.turn_on
    - name: Settings Screen
      show_version: True
      entities:
        - id: backlight
          type: light
        - id: "restart_switch"
          type: switch
        - id: wifi_ssid
          type: text_sensor
        - id: wifi_signal_percent
          type: sensor
        - id: wifi_ip
          type: text_sensor
```

landonr, 2023-07-31:
I haven't actually done any work with touch screens. Are you interested in using this with a touch screen? I figured the device would be too small

You can keep the substitution for `screen_left_pin` and right and remove your duplicate binary sensor

sammcj, 2023-08-10:
Ahhhh ok sorry I didn't realise that!

I was was interested to try it out as I'm looking at options for a home-assistant remote, something to trigger scenes, adjust lights etc... and your project looked like it might make it easy for me to do that. But no worries at all if it was never built with touch in mind I'll have a hack on something myself.

Thanks :)

Closed 2023-08-10.

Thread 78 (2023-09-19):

Hi , I have a proble about rotary

goxofy, 2023-09-19:
**Describe the bug**
I found this project long long ago, I use a Lilygo T-Display TTGO with Adafruit ANO Scrollwheel for this project. It works well.

After an esphome update recently, my remote doesn't work, it seems like esphome changed something about the fonts, it report bug while complie, so I tried to use the latest main branch to flash my device.

While I flashed successfully and it works well except the rotary, I rotated it but the screen has nothing changed. So I have reviewd the code and compare the latest code with my old one, and I found the rotary PIN is changed in latest branch, eg:

```
          PIN                latest                 old longlong ago
  rotary_pin_a                 21                           12
  rotary_pin_b                 22                           13
  rotary_left_pin              15                           21
  rotary_right_pin             12                           17
  rotary_up_pin                2                            22
  rotary_down_pin              13                           2
  rotary_select_pin            17                           15
```

 I tried change the PIN in my configuration with the `substitutions` code, but it still doesn't work.

So what I want to know is whether there are any other changes to this rotary?

Thanks a lot!

landonr, 2023-09-20:
I'm not sure why it's not working. Here's an up to date config with substitutions. https://github.com/landonr/homeThing/blob/main/tdisplay-s3.yaml

Can you looking into this file to see if anything needs changing for your config? You can copy it into your config if you comment out the package include line https://github.com/landonr/homeThing/blob/main/common/ipod/lilygo_tdisplay_ipod_binary_sensor.yaml

landonr, 2023-10-05:
@goxofy did you get anywhere with this?

goxofy, 2023-10-05:
sorry I havent done with this.

Closed 2023-10-05.

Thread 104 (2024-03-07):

Error with PCF8574

jorgeassuncao, 2024-03-07:
**Describe the bug**
installed ESPhome and after flashing i get this error on the log. PCF8574 is soldered in the right position.

**log**
```
ESP-ROM:esp32s3-20210327
Build:Mar 27 2021
rst:0x15 (USB_UART_CHIP_RESET),boot:0x8 (SPI_FAST_FLASH_BOOT)
Saved PC:0x40378c72
invalid header: 0xffffff7f
invalid header: 0xffffff7f
invalid header: 0xffffff7f
SPIWP:0xee
mode:DIO, clock div:1
load:0x3fce3808,len:0x43c
load:0x403c9700,len:0xbec
load:0x403cc700,len:0x2a3c
entry 0x403c98d8
[I][logger:359]: Log initialized
[I][homething.nowplaying.control:017]: set_media_player_group null 1
[W][homething.menu.display:010]: Boot setup
[I][app:029]: Running through setup()...
[I][i2c.arduino:183]: Performing I2C bus recovery
[   463][E][Wire.cpp:513] requestFrom(): i2cRead returned Error -1
[E][pcf8574:012]: PCF8574 not available under 0x20
[E][component:113]: Component pcf8574 was marked as failed.

```

landonr, 2024-03-10:
try turning on `  scan: true` and see if it shows up as another address

jorgeassuncao, 2024-03-10:
Ok, i've added `scan: true` and i'm getting this:

`[C][logger:447]: Logger:
[C][logger:448]:   Level: DEBUG
[C][logger:449]:   Log Baud Rate: 115200
[C][logger:451]:   Hardware UART: USB_CDC
[C][i2c.arduino:053]: I2C Bus:
[C][i2c.arduino:054]:   SDA Pin: GPIO18
[C][i2c.arduino:055]:   SCL Pin: GPIO17
[C][i2c.arduino:056]:   Frequency: 50000 Hz
[C][i2c.arduino:059]:   Recovery: bus successfully recovered
[I][i2c.arduino:069]: Results from i2c bus scan:
[I][i2c.arduino:075]: Found i2c device at address 0x38`

What do i have to change to make this work?

landonr, 2024-03-13:
you can edit substitutions for those lines like this
https://github.com/landonr/homeThing/blob/58bd93a40121b548a5b176bffd16370f56bc546f/tdisplay-s3.yaml#L78

jorgeassuncao, 2024-03-16:
Changed the substitutions code to:

`substitutions:
  friendly_name: "s3 homething"
  rotary_pin_a: "10"
  rotary_pin_b: "11"
  medium_font_size: "16"
  # sda_pin: "18"
  # scl_pin: "17"
  # screen_left_pin: "GPIO0"
  # screen_right_pin: "GPIO14"
  battery_pin: "4"
  # log_level: "DEBUG"
  launch_image_size: 100x100
  launch_image_file: "https://freight.cargo.site/w/450/i/6e34213b4c7e34285aa1729af3f7f0bd6c2d21412ca40407073d7ec8be40ed7c/E75A57A1-8ACD-4004-A603-647BF7AD04F7_1_105_c.jpeg"
  launch_image_type: "RGBA"

  # common/nowPlayingImage.yaml
  online_image_id: "media_player_image"
  online_image_initial_url: "http://172.16.1.23:8080/insecure/rs:fill:170:170/"
  online_image_text_sensor_id: "entity_picture"
  online_image_text_sensor_entity_id: "sensor.beam_picture_proxy"
  online_image_display_id: "my_display"

  # pcf8574
  address: "0x20"`

  But now when compiling i get this error:

  `INFO ESPHome 2024.2.2
INFO Reading configuration /config/esphome/homething.yaml...
INFO Updating https://github.com/landonr/homeThing@main
INFO Updating https://github.com/landonr/lilygo-tdisplays3-esphome.git@v0.1
INFO Updating https://github.com/landonr/homeThing.git@None
INFO Updating https://github.com/landonr/esphome-components@main
INFO Detected timezone 'Europe/Lisbon'
WARNING GPIO0 is a strapping PIN and should only be used for I/O with care.
Attaching external pullup/down resistors to strapping pins can cause unexpected failures.
See https://esphome.io/guides/faq.html#why-am-i-getting-a-warning-about-strapping-pins
WARNING GPIO3 is a strapping PIN and should only be used for I/O with care.
Attaching external pullup/down resistors to strapping pins can cause unexpected failures.
See https://esphome.io/guides/faq.html#why-am-i-getting-a-warning-about-strapping-pins
INFO Generating C++ source...
INFO Compiling app...
Processing lilygos3 (board: esp32-s3-devkitc-1; framework: arduino; platform: platformio/espressif32@5.4.0)
--------------------------------------------------------------------------------
HARDWARE: ESP32S3 240MHz, 320KB RAM, 8MB Flash
 - toolchain-riscv32-esp @ 8.4.0+2021r2-patch5
 - toolchain-xtensa-esp32s3 @ 8.4.0+2021r2-patch5
Dependency Graph
|-- WiFi @ 2.0.0
|-- ESPmDNS @ 2.0.0
|-- Update @ 2.0.0
|-- Wire @ 2.0.0
|-- ArduinoJson @ 6.18.5
|-- WiFiClientSecure @ 2.0.0
|-- HTTPClient @ 2.0.0
|-- pngle @ 1.0.0
|-- TFT_eSPI @ 2.5.43
Compiling .pioenvs/lilygos3/src/esphome/components/font/font.cpp.o
Compiling .pioenvs/lilygos3/src/esphome/components/homeThing/homeThingMenuBase.cpp.o
In file included from src/esphome/components/font/font.cpp:1:
src/esphome/components/font/font.h:53:8: error: 'void esphome::font::Font::print(int, int, esphome::display::Display*, esphome::Color, const char*, esphome::Color)' marked 'override', but does not override
   void print(int x_start, int y_start, display::Display *display, Color color, const char *text,
        ^~~~~
*** [.pioenvs/lilygos3/src/esphome/components/font/font.cpp.o] Error 1
In file included from src/esphome/components/homeThingDisplayState/homeThingDisplayState.h:5,
                 from src/esphome/components/homeThing/homeThingMenuHeader.h:6,
                 from src/esphome/components/homeThing/homeThingMenuBoot.h:9,
                 from src/esphome/components/homeThing/homeThingMenuBase.h:10,
                 from src/esphome/components/homeThing/homeThingMenuBase.cpp:1:
src/esphome/components/font/font.h:53:8: error: 'void esphome::font::Font::print(int, int, esphome::display::Display*, esphome::Color, const char*, esphome::Color)' marked 'override', but does not override
   void print(int x_start, int y_start, display::Display *display, Color color, const char *text,
        ^~~~~
*** [.pioenvs/lilygos3/src/esphome/components/homeThing/homeThingMenuBase.cpp.o] Error 1
========================== [FAILED] Took 4.65 seconds ==========================`

Do you have any idea?

landonr, 2024-03-24:
You can remove the `font` component because it's merged into ESPHome now. I updated the example config

jorgeassuncao, 2024-03-25:
Lots of errors when compiling...

```
INFO ESPHome 2024.2.2
INFO Reading configuration /config/esphome/homething.yaml...
INFO Updating https://github.com/landonr/homeThing@main
INFO Updating https://github.com/landonr/lilygo-tdisplays3-esphome.git@v0.1
INFO Updating https://github.com/landonr/homeThing.git@None
INFO Updating https://github.com/landonr/esphome-components@main
INFO Detected timezone 'Europe/Lisbon'
WARNING GPIO0 is a strapping PIN and should only be used for I/O with care.
Attaching external pullup/down resistors to strapping pins can cause unexpected failures.
See https://esphome.io/guides/faq.html#why-am-i-getting-a-warning-about-strapping-pins
WARNING GPIO3 is a strapping PIN and should only be used for I/O with care.
Attaching external pullup/down resistors to strapping pins can cause unexpected failures.
See https://esphome.io/guides/faq.html#why-am-i-getting-a-warning-about-strapping-pins
Failed config

font: [source /data/packages/c523de9d/common/fonts.yaml:7]
  -
    Unknown value 'web', valid options are 'local', 'gfonts', 'local_bitmap'.
    file:
      url: https://github.com/landonr/homeThing/raw/main/fonts/iosevka-heavy.ttf
      type: web
    id: large_heavy_font
    size: 24
    glyphs: |-
      ^…*/|\$#<>!?"%()[]+=,-_.:°0123456789ABCDEFGHIJKLMNOPQRSTUVWXYZ abcdefghijklmnopqrstuvwxyz&êÊîÎâÂôÔéÉíÍáÁóÓčëËüÜïÏöÖøØṣṢñãõÑÃÕ'’
  -
    Unknown value 'web', valid options are 'local', 'gfonts', 'local_bitmap'.
    file:
      url: https://github.com/landonr/homeThing/raw/main/fonts/iosevka.ttf
      type: web
    id: large_font
    size: 24
    glyphs: |-
      ^…*/|\$#<>!?"%()[]+=,-_.:°0123456789ABCDEFGHIJKLMNOPQRSTUVWXYZ abcdefghijklmnopqrstuvwxyz&êÊîÎâÂôÔéÉíÍáÁóÓčëËüÜïÏöÖøØṣṢñãõÑÃÕ'’
  -
    Unknown value 'web', valid options are 'local', 'gfonts', 'local_bitmap'.
    file:
      url: https://github.com/landonr/homeThing/raw/main/fonts/iosevka.ttf
      type: web
    id: medium_font
    size: 16
    glyphs: |-
      ^…*/|\$#<>!?"%()[]+=,-_.:°0123456789ABCDEFGHIJKLMNOPQRSTUVWXYZ abcdefghijklmnopqrstuvwxyz&êÊîÎâÂôÔéÉíÍáÁóÓčëËüÜïÏöÖøØṣṢñãõÑÃÕ'’
  -
    Unknown value 'web', valid options are 'local', 'gfonts', 'local_bitmap'.
    file:
      url: https://github.com/landonr/homeThing/raw/main/fonts/iosevka.ttf
      type: web
    id: small_font
    size: 14
    glyphs: |-
      ^…*/|\$#<>!?"%()[]+=,-_.:°0123456789ABCDEFGHIJKLMNOPQRSTUVWXYZ abcdefghijklmnopqrstuvwxyz&êÊîÎâÂôÔéÉíÍáÁóÓčëËüÜïÏöÖøØṣṢñãõÑÃÕ'’
  -
    Could not find file '/config/esphome/https://github.com/landonr/homeThing/raw/main/fonts/materialdesignicons-webfont.ttf'. Please make sure it exists (full path: /config/esphome/https:/github.com/landonr/homeThing/raw/main/fonts/materialdesignicons-webfont.ttf).
    file: |-
      https://github.com/landonr/homeThing/raw/main/fonts/materialdesignicons-webfont.ttf
    id: material_font_large
    size: 19
    glyphs:
      - 󰐊
      - 󰓛
      - 󰏤
      - 󰽥
      - 󰒝
      - 󰒞
      - 󰕾
      - 󰕿
      - 󰚺
      - 󰝆
      - 󰗃
      - 󰓇
      - 󰔂
      - 󰋜
      - 󰌵
      - 󰌶
      - 󰑗
      - 󰑘
      - 󰑖
  -
    Could not find file '/config/esphome/https://github.com/landonr/homeThing/raw/main/fonts/materialdesignicons-webfont.ttf'. Please make sure it exists (full path: /config/esphome/https:/github.com/landonr/homeThing/raw/main/fonts/materialdesignicons-webfont.ttf).
    file: |-
      https://github.com/landonr/homeThing/raw/main/fonts/materialdesignicons-webfont.ttf
    id: material_font_small
    size: 18
    glyphs:
      - 󰐊
      - 󰓛
      - 󰏤
      - 󰽥
      - 󰒝
      - 󰒞
      - 󰕾
      - 󰕿
      - 󰚺
      - 󰝆
      - 󰗃
      - 󰓇
      - 󰔂
      - 󰋜
      - 󰌵
      - 󰌶
      - 󰑗
      - 󰑘
      - 󰑖
```

landonr, 2024-03-26:
`INFO ESPHome 2024.2.2` update to ESPHome 2024.3.0

ssttaarr33, 2024-05-10:
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

Did you find out what was the issue? I'm facing the same one

jorgeassuncao, 2024-05-10:
Hi @ssttaarr33

The suggested substitutions code `address: "0x20"` on the `homeThing/tdisplay-s3.yaml` file did not work but the errors i had compiling disappeared after the update of ESPHome to v2024.3.0.

The only way i got it working was cloning the repo and change the file `/common/ipod/lilygo_tdisplay_ipod_binary_sensor_pcf.yaml` to use the correct address.

landonr, 2024-05-14:
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

thanks @jorgeassuncao I'll try to update the example to use variables instead of substitutions

jorgeassuncao, 2024-05-14:
Sorry for not giving feedback earlier...

Closed 2024-05-10.

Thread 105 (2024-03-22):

Error setting up the yaml

JoeGandy, 2024-03-22:
**Describe the bug**
```
Failed config

binary_sensor.gpio: [source /config/.esphome/packages/c523de9d/common/ipod/lilygo_tdisplay_ipod_binary_sensor_pcf.yaml:17]

  Pin 0 incorrectly sets allow_other_uses: true.
  platform: gpio
  pin:
    number: 0
    allow_other_uses: True
    inverted: True
```
Commenting line
` common/ipod/lilygo_tdisplay_ipod_binary_sensor_pcf.yaml, # used for button controls` resolves the issue, but obviously breaks buttons
**To Reproduce**
Steps to reproduce the behavior:
1. Using default yaml: https://raw.githubusercontent.com/landonr/homeThing/main/tdisplay-s3.yaml

**Desktop (please complete the following information):**
 - OS: [e.g. iOS]
 - Browser [e.g. chrome, safari]
 - Version [e.g. 22]

**Smartphone (please complete the following information):**
 - Device: [e.g. iPhone6]
 - OS: [e.g. iOS8.1]
 - Browser [e.g. stock browser, safari]
 - Version [e.g. 22]

**Additional context**
Add any other context about the problem here.

JoeGandy, 2024-03-22:
Potentially caused by https://github.com/landonr/homeThing/commit/416c33fd72800b0393d2b0d5d31eb39fc5a8230a

?

landonr, 2024-03-24:
@JoeGandy I updated the yaml.

if you want to use the config locally use can do this. The file has to be available locally so you can copy it into your esphome folder
```yaml
packages: # maybe modify: include default ipod controls
  -+ ipod_control_binary_sensor_pcf: !include ../homeThing/common/ipod/lilygo_tdisplay_ipod_binary_sensor_pcf.yaml
  remote_package:
    url: https://github.com/landonr/homeThing
    ref: main
    files: [
      common/device_base.yaml, # defines api, ota, free memory and uptime sensor
      common/ipod/lilygo_tdisplay_ipod_battery.yaml, # used for battery percent
      # comment this out! common/ipod/lilygo_tdisplay_ipod_binary_sensor_pcf.yaml, # used for button controls
```

Closed 2024-03-24.

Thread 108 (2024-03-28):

Menu doesn't line up if it refreshes and changes size

landonr, 2024-03-28:
**To Reproduce**
Steps to reproduce the behavior:
1. start the device with a media player with grouping
2. wait for boot to complete
3. select an item after grouping
4. it goes to the item before the index selected

**Expected behavior**
the right index is selected

**Additional context**
the menu is reloaded but the selection list isnt

Closed 2024-04-28.

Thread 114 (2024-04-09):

add image app

landonr, 2024-04-09:
**Is your feature request related to a problem? Please describe.**
would be nice for showing cameras

**Describe the solution you'd like**
new app that shows online image

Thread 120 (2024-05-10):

Problem with order from pcbway.com

Shiroe93, 2024-05-10:
I order the manufacturing of your project from your project page but the sales reps need to know more details about the case such as how to assembly, if it needs threads etc.
Can you please provide me the details or respond to the details request from the rep on pcbway.com directly?
Thank you

11mila, 2024-05-15:
Hi i'm mila from PCBWay. We got reply from author. The author said the case shouldn't need threads but it would help. And he is  working on a build quide which should help.

landonr, 2024-06-20:
https://www.youtube.com/watch?v=hcDLqpd2mt0

Closed 2024-06-20.

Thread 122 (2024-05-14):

Error on compilation for StickCplus: component not found

Aaroneisele55, 2024-05-14:
**Describe the bug**
The compilation fails with the error "Component not found: homeThing."

**To Reproduce**
Steps to reproduce the behavior:
1. Use the M5StickCplus example code
2. try to compile
3. get the above error

**Expected behavior**
It should just work

**Logs**

[logs_m5stickcplus-homething_compile.txt](https://github.com/landonr/homeThing/files/15312209/logs_m5stickcplus-homething_compile.txt)

**Desktop (please complete the following information):**
 - OS: Windows
 - Browser Chrome
 - Version 11

**Additional context**
Add any other context about the problem here.

landonr, 2024-05-24:
can you share your full config? In the M5StickCPlus example homeThing is included here https://github.com/landonr/homeThing/blob/b976359ad3ab50d78f41c66a298985b5b1e51c60/m5stack-stickc.yaml#L26

we can see the project is building properly here https://github.com/landonr/homeThing/actions/runs/9216531658/job/25357000146

Aaroneisele55, 2024-05-24:
This is my config:
```
esphome:
  name: m5stickcexample
  friendly_name: m5stickcexample

esp32:
  board: m5stick-c
  framework:
    type: arduino

# Enable logging
logger:

# Enable Home Assistant API
api:

ota:

wifi:
  ssid: !secret wifi_ssid
  password: !secret wifi_password

substitutions:
  friendly_name: "homeThingM5StickPlus"

external_components:
  - source:
      type: git
      url: https://gitlab.com/geiseri/esphome_extras.git
    refresh: 0s
    components: [axp192]
  - source:
      type: git
      url: https://github.com/landonr/homeThing
      ref: main
    refresh: 0s
    components: [homeThing]
  - source:
      type: git
      url: https://github.com/landonr/esphome-components
      ref: main
    refresh: 0s
    components: [
      homeassistant_component,
      homeassistant_media_player,
      media_player_source,
      media_player_source_sonos,
      media_player_source_spotify,
      media_player_source_custom
    ]

packages:
  remote_package:
    url: https://github.com/landonr/homeThing
    ref: main
    files: [
      common/device_base.yaml, # defines api, ota, free memory and uptime sensor
      common/fonts.yaml, # default font
      common/icon_fonts.yaml # material icons
    ]
    refresh: 0s

i2c:
   - id: bus_a
     sda: GPIO21
     scl: GPIO22
     scan: true
   - id: bus_b
     sda: GPIO0
     scl: GPIO26
     scan: true

axp192:
  id: axp
  i2c_id: bus_a
  address: 0x34
  update_interval: 60s
  charge_voltage: 4150mV
  dcdc1_voltage: 3300mv
  dcdc3_voltage: 1.5V

sensor:
    # AXP192 power management - must be present to initialize TFT power on
  - platform: axp192
    axp192_id: axp
    id: battery_percent
    type: battery_power
    name: "${friendly_name} Battery Percent"

# internal LED
light:
  - platform: monochromatic
    output:  builtin_led
    name: Led
    id: led1
    internal: True
  - platform: monochromatic
    output: axp_ldo3
    name: "${friendly_name} Backlight"
    id: backlight
    restore_mode: ALWAYS_ON

output:
  - platform: ledc
    pin: 10
    inverted: true
    id: builtin_led
  - platform: axp192
    axp192_id: axp
    output: ldo3
    id: axp_ldo3

binary_sensor:
  - platform: axp192
    axp192_id: axp
    type: charge_indicate
    id: axp_charger
    name: "Charger"
  - platform: gpio
    pin:
      number: GPIO37
      inverted: true
    name: Button A
    on_click:
      min_length: 5ms
      max_length: 350ms
      then:
        lambda: |-
            id(homeThingMenu)->rotaryScrollClockwise(0);
            auto call = id(led1).turn_on();
            call.set_transition_length(0);
            call.perform();
    on_multi_click:
    - timing:
        - ON for at least 0.5s
      then:
      - lambda: |-
          id(homeThingMenu)->buttonPressUp();
    on_release:
      then:
        - light.turn_off: led1
  - platform: gpio
    pin:
      number: GPIO39
      inverted: true
    name: Button B
    on_press:
      then:
      - lambda: |-
          id(homeThingMenu)->buttonPressSelect();
          auto call = id(led1).turn_on();
          call.set_transition_length(0);
          call.perform();
    on_release:
      then:
        - light.turn_off: led1

deep_sleep:
  id: deep_sleep_
  wakeup_pin: 37
  wakeup_pin_mode: INVERT_WAKEUP

switch:
  - platform: axp192
    axp192_id: axp
    output: ldo3
    name: LDO3
    internal: true
  - platform: template
    name: "${friendly_name} Sleep Toggle"
    id: sleep_toggle
    optimistic: true
    on_turn_on:
      then:
        - light.turn_off:
            id: backlight
            transition_length: 0s
        - delay: 0.5s
        - deep_sleep.enter:
            id: deep_sleep_

spi:
  clk_pin: GPIO13
  mosi_pin: GPIO15

display:
  - platform: st7789v
    model: TTGO_TDisplay_135x240
    id: my_display
    cs_pin: GPIO5
    dc_pin: GPIO23
    reset_pin: GPIO18
    rotation: 0
    update_interval: 3600s
    lambda: |-
      id(homeThingMenu)->draw_menu_screen();
      return;

media_player_source_sonos:
  id: sonos

media_player_source_spotify:
  id: spotty

media_player_source_custom:
  - id: fav_playlists
    name: playlists
    sources:
      - name: Radio 7
        media_id: "aac://https://radio7.streamabc.net/87-radio7dab-aac-128-7982739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;skey:1711457341"
        media_type: music
      - name: DasDing
        media_id: "aac://https://d121.rndfnk.com/ard/swr/dasding/live/aac/96/stream.aac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"
        media_type: music

media_player:
  - platform: homeassistant_media_player
    name: Beam
    entity_id: "media_player.sonos_aaron_2"
    id: media_player_sonos_aaron
    type: speaker
    sources:
      - id: sonos
        type: sonos
      - id: spotty
        type: spotify
      - id: fav_playlists
        type: custom
homeassistant_media_player:
  id: media_group_component
  media_players:
    - id: media_player_sonos_aaron
      type: speaker

homeThing:
  id: homeThingMenu
  settings:
    mode: 2_button
  sleep_switch: sleep_toggle
  backlight: backlight
  display: my_display
  on_redraw:
    then:
      component.update: my_display
  display_state:
    font_small: small_font
    font_medium: medium_font
    font_large: large_font
    font_large_heavy: large_heavy_font
    font_material_large: material_font_large
    font_material_small: material_font_small
    font_logo: home_thing_logo
    draw_now_playing_bottom_menu: True
```

landonr, 2024-05-25:
@Aaroneisele55 thanks for sharing, the error its giving isn't that specific.
I moved DisplayState out of the homeThing config so it can be shared with other apps
the following should work
```yaml
esphome:
  name: m5stickcexample
  friendly_name: m5stickcexample

esp32:
  board: m5stick-c
  framework:
    type: arduino

# Enable logging
logger:

# Enable Home Assistant API
api:

ota:

wifi:
  ssid: !secret wifi_ssid
  password: !secret wifi_password

substitutions:
  friendly_name: "homeThingM5StickPlus"

external_components:
  - source:
      type: git
      url: https://gitlab.com/geiseri/esphome_extras.git
    refresh: 0s
    components: [axp192]
  - source:
      type: git
      url: https://github.com/landonr/homeThing
      ref: main
      # type: local
      # path: ../homeThing/components
    refresh: 0s
    components: [homeThing, homeThingDisplayState, homeThingApp, homeThingAppNowPlaying, homeThingAppBreakout ]
  - source:
      type: git
      url: https://github.com/landonr/esphome-components
      ref: main
    refresh: 0s
    components: [
      homeassistant_component,
      homeassistant_media_player,
      media_player_source,
      media_player_source_sonos,
      media_player_source_spotify,
      media_player_source_custom
    ]

packages:
  remote_package:
    url: https://github.com/landonr/homeThing
    ref: main
    files: [
      common/device_base.yaml, # defines api, ota, free memory and uptime sensor
      common/fonts.yaml, # default font
      common/icon_fonts.yaml # material icons
    ]
    refresh: 0s

i2c:
   - id: bus_a
     sda: GPIO21
     scl: GPIO22
     scan: true
   - id: bus_b
     sda: GPIO0
     scl: GPIO26
     scan: true

axp192:
  id: axp
  i2c_id: bus_a
  address: 0x34
  update_interval: 60s
  charge_voltage: 4150mV
  dcdc1_voltage: 3300mv
  dcdc3_voltage: 1.5V

sensor:
    # AXP192 power management - must be present to initialize TFT power on
  - platform: axp192
    axp192_id: axp
    id: battery_percent
    type: battery_power
    name: "${friendly_name} Battery Percent"
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
Aaroneisele55, 2024-05-27:
OK, so it boots correctly now, but how can I go back from a page?
I tried button A, B, and long press on each of them, but I didn't succeed...

Thanks for your help
Aaron

Aaroneisele55, 2024-05-27:
Thanks for your help, now it boots!

How can I make it control a light that is connected to HA (entity_id: light.wled)?

Best regards
Aaron

landonr, 2024-05-28:
@Aaroneisele55 you may need to enable API control, if you go to `http://homeAssistant:8123/config/integrations/integration/esphome`, click `Configure` on your device, then check the box

Aaroneisele55, 2024-05-28:
> @Aaroneisele55 you may need to enable API control, if you go to `http://homeAssistant:8123/config/integrations/integration/esphome`, click `Configure` on your device, then check the box for **Allow the device to make Home Assistant service calls.**

I have enabled it, but it still doesn't work...
Also, the device shuts itself down after ~30 seconds, even when the charger is plugged in

landonr, 2024-05-29:
@Aaroneisele55 it might be crashing? If you have any error logs it might help.

I haven't tested a wled light, but sonos and a other types of lights are tested on my side

The stickcplus doesn't have much ram. I use my StickCPlus to control one led strip plugged into it, and to change light scenes using service calls, othertwise it runs out of memory. Can you try a simpler config and see if the device will stay on

Aaroneisele55, 2024-05-29:
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

What would that simpler config be?
I only really need control of 6 lights and one input_boolean, as well as status display of four binary sensors

Closed 2024-07-31.

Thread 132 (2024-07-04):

Media player online image is not generated

iondulgheru, 2024-07-04:
Media player online image is not generated.
I added in HA the template sensor to create the sensor media_player_image_proxy_url. I also installed and configured imgproxy, I use it a docker container, I can't install it as an addon, as I use HA in docker, but it works properly anyway.
I think the problem is that this template should get the attribute entity_picture from a sensor called active_player.
No such sensor is defined in HA, I see that is defined in the HomeThing code, but is not exported to HA.
If I change the template to get this attribute from the the media_player I am using image generation works.
I think the active_player sensor should also be exposed to HA.
Or maybe i am doing something wrong?
I am using https://github.com/landonr/homeThing/blob/main/tdisplay-s3.yaml

landonr, 2024-07-05:
youre right it's missing from the example code! I added it in #133, it's like this

```
homeassistant_media_player: # media player menu
  id: media_group_component
  finished_loading:
    id: media_players_loaded_sensor
  active_player:
    id: active_player
    name: "${friendly_name} Active Player"
  media_players:
    - id: media_player_beam
      type: speaker
    - id: media_player_tv
      type: roku
```

iondulgheru, 2024-07-05:
Thank you!

iondulgheru, 2024-07-05:
Also this "https://" concatenation breaks the link, which looks like "https://http://[...]", if it the HA template is defined according to the example
https://github.com/landonr/homeThing/blob/main/common/nowPlayingImage.yaml#L44

landonr, 2024-07-05:
I have to remove the `http` from the example url. Last time I checked, the online image code couldn't handle unencrypted urls (http). Is `http://` being added anywhere else?

iondulgheru, 2024-07-05:
In my case it works without any issues over http. Right now I have defined the full url (with http) in the HA template, and on esphome I removed the https concatenation. In my setup it doesn't work over https, I tried it.
These are the only changes I made, and it works.

landonr, 2024-07-05:
@iondulgheru I http is fixed! Http and https are both working for external images now. I updated #133 with updated instructions and i'll try to add a readme to https://github.com/landonr/esphome-components/tree/main/components/homeassistant_media_player
@guillempages

iondulgheru, 2024-07-05:
Thank you @landonr 🙏

Closed 2024-07-05.

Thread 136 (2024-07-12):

m5 Stick Config Failing: "Unable to find action with the name 'homething_menu.scroll_counter_clockwise'."

barndawgie, 2024-07-12:
I'm trying to install homeThing to a brand new m5Stack FIRE device. When I try to validate the configuration in ESPHome Dashboard, I'm getting a failure: "Unable to find action with the name 'homething_menu.scroll_counter_clockwise'."

Here is my config, heavily based on your wiki and samples:

```yaml
---
substitutions:
  name: "home-thing"
  friendly_name: "homeThing"
  device_description: esp32 homeThing Remote Control
  board: m5stack-fire
  variant: esp32

packages:
  remote_package:
    url: https://github.com/landonr/homeThing
    ref: main
    files: [ # See https://github.com/landonr/homeThing/blob/main/GettingStarted.md
      common/device_base.yaml, # defines api, ota, free memory and uptime sensor
      common/m5stack-fire/backlight.yaml, # used for toggling backlight
      common/m5stack-fire/binary_sensor.yaml, # used for button controls
      common/m5stack-fire/binary_sensor_rotary.yaml, # used for rotary controls
      common/m5stack-fire/ip5306.yaml, # used for battery percent
      common/m5stack-fire/sidelight.yaml, # used to control LED strip
      common/fonts.yaml, # default font
      common/icon_fonts.yaml, # material icons
      common/images.yaml, # boot screen image
    ]
  base_config: !include config_deps/base_config.yaml

external_components:
  - source: # homeThing, display setup, and now playing app
      type: git
      url: https://github.com/landonr/homeThing
      ref: main
    refresh: 0s
    components: [
      homeThing,
      homeThingDisplayState,
      homeThingApp, # only required if using apps
      homeThingAppNowPlaying # only required for Now Playing app
    ]
  - source:
      type: git
      url: https://github.com/landonr/esphome-components
      ref: main
    refresh: 0s
    components: [
      homeassistant_component,
      homeassistant_media_player,
      media_player_source,
      media_player_source_sonos,
      media_player_source_spotify,
      media_player_source_custom
    ]
  - source:
      type: git
      url: https://github.com/ssieb/custom_components
    components: [ ip5306 ]

esphome:
  name: ${name}
  friendly_name: ${friendly_name}
  comment: ${device_description}

esp32:
  board: ${board}
  framework:
    type: esp-idf
  variant: ${variant}
```

Here is what I get from validate using ESPHome 2024.6.6 Dashboard:
```
INFO ESPHome 2024.6.6
INFO Reading configuration /config/home-thing.yaml...
INFO Updating https://github.com/landonr/homeThing@main
INFO Updating https://github.com/landonr/esphome-components@main
INFO Detected timezone 'America/Los_Angeles'
Failed config

binary_sensor.gpio: [source /config/.esphome/packages/c523de9d/common/m5stack-fire/binary_sensor.yaml:2]
  platform: gpio
  id: M5_BtnA
  pin:
    number: 39
    inverted: True
  on_click:
    then:

      Unable to find action with the name 'homething_menu.scroll_counter_clockwise'.
      homething_menu.scroll_counter_clockwise: homeThingMenu
```

I don't _think_ this particular error can be caused by something on my side, but maybe I am missing something...

barndawgie, 2024-07-18:
Thanks for the reply!

>you shouldn't need both of the binary sensor configs. If you don't have the external encoder, just use the binary_sensor otherwise use the rotary one

Makes sense. I removed `binary_sensor_rotary.yaml` but still get the error.

>i noticed base_config: !include config_deps/base_config.yaml can you share this? It might have includes which overwrite includes in the config you shared. For example if you define images in the base config, and then in the package, it's overwritten in the base

This is my own private base config - it just configures WiFi and sets the API Encryption key. I removed it and moved these into the config for debugging simplicity.

> if you remove the binary_sensor.yaml include, are you able to compile and boot into the menu?

No. if I remove `binary_sensor.yaml` I get errors saying that "Component font requires component display." If I remove every package accept `device_base.yaml` I still get errors. Seems like these may also be related to the lack of an m5stack dispaly in the configured files?

```
Failed config

api: [source /config/.esphome/packages/c523de9d/common/device_base.yaml:19]
  id: homeassistant_api_id
  services:
    - service: goto_screen
      variables:
        screen_name: string
      then:
        -
          Couldn't find ID 'homeThingMenu'. Please check you have defined an ID with that name in your configuration.
          lambda: !lambda |-
            id(homeThingMenu)->goToScreenFromString(screen_name);
  encryption:
    key: Rjtway9CYmFqUGNQMVtAOERKI2h7Yz1ZdVgtMDh5KGY=
  port: 6053
  password: ''
time.homeassistant: [source /config/.esphome/packages/c523de9d/common/device_base.yaml:30]
  platform: homeassistant
  id: esptime
  on_time_sync:
    - then:
        - component.update:
    
            Couldn't find ID 'my_display'. Please check you have defined an ID with that name in your configuration.
            id: my_display
  timezone: PST8PDT,M3.2.0,M11.1.0
  update_interval: 15min
```

barndawgie, 2024-07-18:
Seems like I missed a lot of components, really. I was trying to base this off of this wiki (https://github.com/landonr/homeThing/wiki/m5stack-fire) but it contains a mix of what seem like required components and references to your own setup.

Let me spend some time and try to figure out an "empty" m5stack config and maybe I can submit in a PR or something.

landonr, 2024-07-19:
That wiki page is pretty out of date, i'm going to remote it!
I have this example file https://github.com/landonr/homeThing/blob/main/m5stack-fire.yaml which should build. update the entities in there
There's this basic config you can compare it against https://github.com/landonr/homeThing/blob/main/basic.yaml

this is my personal M5Stack Fire config that I use to control my cat's auto feeder https://github.com/landonr/esphome-devices/blob/main/fireremote.yaml

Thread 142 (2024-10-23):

Error in YAML when installing -  Component image requires component display

benji2020, 2024-10-23:
INFO ESPHome 2024.10.1
INFO Reading configuration /config/esphome/ha-remote-1-ipodish.yaml...
INFO Updating https://github.com/landonr/homeThing@main
WARNING Found '${friendly_name} Uptime' (see sensor->0->name) which looks like a substitution, but 'friendly_name' was not declared
WARNING Found '${friendly_name} Battery Percent Internal' (see sensor->4->name) which looks like a substitution, but 'friendly_name' was not declared
WARNING Found '${friendly_name} Battery Percent' (see sensor->5->name) which looks like a substitution, but 'friendly_name' was not declared
WARNING Found '${friendly_name} Backlight' (see light->0->name) which looks like a substitution, but 'friendly_name' was not declared
WARNING Found '${friendly_name} Sleep Toggle' (see switch->0->name) which looks like a substitution, but 'friendly_name' was not declared
WARNING Found '${friendly_name} Uptime' (see sensor->0->name) which looks like a substitution, but 'friendly_name' was not declared
WARNING Found '${friendly_name} Battery Percent Internal' (see sensor->4->name) which looks like a substitution, but 'friendly_name' was not declared
WARNING Found '${friendly_name} Battery Percent' (see sensor->5->name) which looks like a substitution, but 'friendly_name' was not declared
WARNING Found '${friendly_name} Backlight' (see light->0->name) which looks like a substitution, but 'friendly_name' was not declared
WARNING Found '${friendly_name} Sleep Toggle' (see switch->0->name) which looks like a substitution, but 'friendly_name' was not declared
INFO Updating https://github.com/landonr/homeThing@main
INFO Updating https://github.com/landonr/esphome-components@main
INFO Detected timezone 'Europe/London'
Failed config

image: [source /data/packages/c523de9d/common/images.yaml:7]

  Component image requires component display.
  id: launch_image
  file: https://raw.githubusercontent.com/landonr/homeThing/main/docs/homeThingLogo.svg
  resize: 48x48
  type: TRANSPARENT_BINARY
```

landonr, 2024-11-30:
i think this should be fixed now

Closed 2025-01-06.

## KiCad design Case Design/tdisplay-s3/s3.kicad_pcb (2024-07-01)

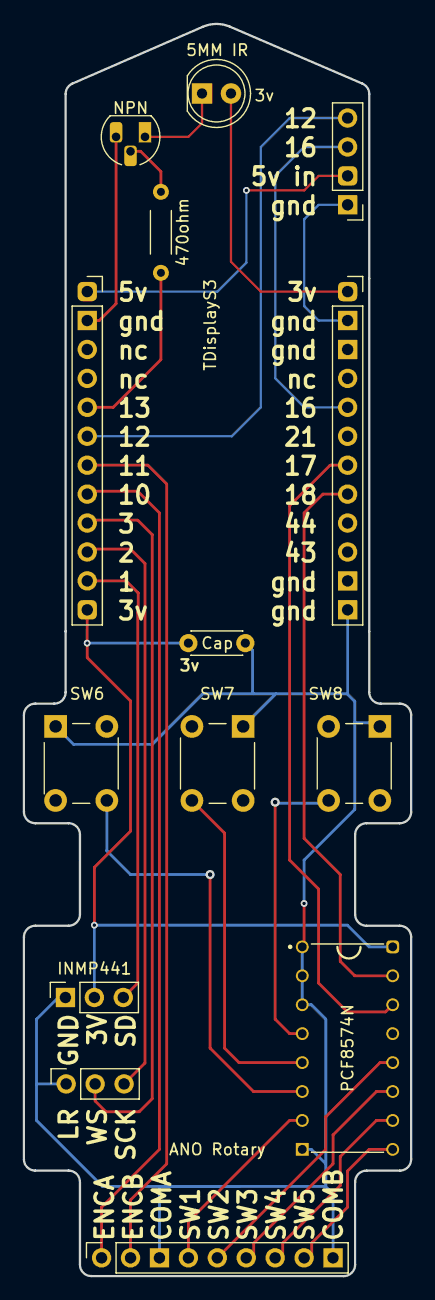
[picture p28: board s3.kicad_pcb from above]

Board: 2 copper layers, 34.0 x 109.9 mm, 12 parts (0 on the bottom side), 17 nets.

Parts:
5MM IR: LED_D5.0mm_Clear
470ohm: R_Axial_DIN0204_L3.6mm_D1.6mm_P5.08mm_Horizontal
ANO Rotary: PinSocket_1x09_P2.54mm_Vertical
Cap: C_Disc_D4.3mm_W1.9mm_P5.00mm
INMP441, INMP441 2: PinSocket_1x03_P2.54mm_Vertical
NPN: TO-92L_HandSolder
PCF8574N: DIP794W45P254L1969H508Q16
SW6, SW7, SW8: SW_PUSH_6mm_H9.5mm
TDisplayS3: PinSocket_1x12_P2.54mm_Vertical

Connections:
3v: Cap.1, INMP441.2, PCF8574N.16, TDisplayS3.12
enca: ANO Rotary.ENCA, TDisplayS3.8
encb: ANO Rotary.ENCB, TDisplayS3.7
ground: ANO Rotary.COMA, ANO Rotary.COMB, Cap.2, INMP441.1, INMP441 2.1, PCF8574N.A0, PCF8574N.A1, PCF8574N.A2, PCF8574N.GND, SW6.1, SW7.2, SW8.2
ground2: NPN.3, TDisplayS3.gnd
irled: 5MM IR.1, 470ohm.1, 470ohm.2, NPN.1, NPN.2, TDisplayS3.5
sck: INMP441 2.3, TDisplayS3.10
sd: INMP441.3, TDisplayS3.11
sw1: ANO Rotary.SW1, PCF8574N.P3
sw2: ANO Rotary.SW2, PCF8574N.P7
sw3: ANO Rotary.SW3, PCF8574N.P6
sw4: ANO Rotary.SW4, PCF8574N.P5
sw5: ANO Rotary.SW5, PCF8574N.P4
sw6: PCF8574N.P2, SW6.2
sw7: PCF8574N.P1, SW7.1
sw8: PCF8574N.P0, SW8.1
ws: INMP441 2.2, TDisplayS3.9

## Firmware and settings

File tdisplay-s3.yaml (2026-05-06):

esphome:
  name: "tdisplay-s3"
  on_boot: 
    then:
    - delay: 0.5s
    - light.turn_on:
        id: backlight
        brightness: 100%
        transition_length: 0.5s

esp32:
  board: esp32-s3-devkitc-1
  variant: esp32s3
  framework:
    type: esp-idf
  flash_size: 16MB

external_components:
  - source: github://landonr/lilygo-tdisplays3-esphome@v0.1
    components: [tdisplays3]
    refresh: 0s
  - source: github://landonr/homeThing@main #update_to_head_ref
  # - source:      
  #     type: local
  #     path: components
    refresh: 0s
    components: [homeThing, homeThingDisplayState, homeThingApp, homeThingAppNowPlaying, homeThingAppSnake, homeThingAppCatToy, homeThingAppBreakout, homeThingAppWeather]
  - source:
      type: git
      url: https://github.com/landonr/esphome-components
      ref: main
    refresh: 0s
    components: [
      homeassistant_component,
      homeassistant_media_player,
      media_player_source,
      media_player_source_sonos,
      media_player_source_spotify,
      media_player_source_custom
    ]
  
packages: 
  # common
  device_base: github://landonr/homeThing/common/device_base.yaml@main
  fonts: github://landonr/homeThing/common/fonts.yaml@main
  icon_fonts: github://landonr/homeThing/common/icon_fonts.yaml@main
  settings: github://landonr/homeThing/common/settings.yaml@main
  images: github://landonr/homeThing/common/images.yaml@main
  nowPlayingImage: github://landonr/homeThing/common/nowPlayingImage.yaml@main
  voice_assistant: github://landonr/homeThing/common/voice_assistant.yaml@main
  logger: github://landonr/homeThing/common/logger.yaml@main

  # ipod
  battery: github://landonr/homeThing/common/ipod/lilygo_tdisplay_ipod_battery.yaml@main
  sleep: github://landonr/homeThing/common/ipod/lilygo_tdisplay_ipod_sleep.yaml@main
  rotary: github://landonr/homeThing/common/ipod/lilygo_tdisplay_ipod_rotary.yaml@main

  #tdisplay s3
  backlight: github://landonr/homeThing/common/tdisplay-s3/backlight.yaml@main
  binary_sensors: github://landonr/homeThing/common/tdisplay-s3/lilygo_tdisplay_ipod_binary_sensor_pcf.yaml@main
  # rotary_seesaaw: !include github://landonr/homeThing/common/tdisplay-s3/lilygo_tdisplay_ipod_rotary_seesaw.yaml@main
  # binary_sensor_seesaw: !include github://landonr/homeThing/common/tdisplay-s3/lilygo_tdisplay_ipod_binary_sensor_seesaw.yaml@main

substitutions:
  friendly_name: "homeThing S3"
  rotary_pin_a: "10"
  rotary_pin_b: "11"
  medium_font_size: "16"
  battery_pin: "4"

  # common/nowPlayingImage.yaml
  online_image_id: "media_player_image"
  online_image_initial_url: "http://172.16.1.23:8080/insecure/rs:fill:170:170/"
  online_image_text_sensor_id: "entity_picture"
  online_image_text_sensor_entity_id: "sensor.beam_picture_proxy"
  online_image_display_id: "my_display"

light: # home assistant lights
  - platform: homeassistant_component
    id: light_all_lights
    entity_id: light.all_lights
    name: All Lights

    # plugged into Stemma QT port
  - platform: esp32_rmt_led_strip
    chipset: WS2812
    rgb_order: RGB
    pin: GPIO43
    num_leds: 42
    name: "${friendly_name} Strip Light"
    restore_mode: RESTORE_DEFAULT_OFF
    id: strip_light
    default_transition_length: 0s
    effects:
      - addressable_rainbow:
          name: Rainbow Effect
          speed: 10
          width: 50

### Media Players

media_player_source_sonos: # sonos favorite source
  id: sonos

media_player: # home assistant media players
  - platform: homeassistant_media_player
    name: Beam
    entity_id: "media_player.beam"
    id: media_player_beam
    type: speaker
    sources:
      - id: sonos
        type: sonos
  - platform: homeassistant_media_player
    name: TV
    entity_id: "media_player.55_tcl_roku_tv"
    id: media_player_tv
    type: roku
    soundbar:
      speaker: media_player_beam

homeassistant_media_player: # media player menu
  id: media_group_component
  finished_loading:
    id: media_players_loaded_sensor
  active_player: 
    id: active_player
    name: "${friendly_name} Active Player"
  media_players:
    - id: media_player_beam
      type: speaker
    - id: media_player_tv
      type: roku

homeThingAppNowPlaying:
  display: my_display
  display_state: display_state_id
  id: now_playing
  media_player_group: media_group_component
  now_playing_image: media_player_image

### Covers / Smart Desk

number: # home assistant number
  - platform: homeassistant_component
    entity_id: number.desk_height_cm
    name: desk height
    id: desk_height_number
    min_value: 61.0
    max_value: 105.0
    step: 1

cover: # home assistant cover
  - platform: homeassistant_component
    entity_id: "cover.megadesk_cover"
    name: "Megadesk"
    id: cover_megadesk

### Weather

sensor:
  - platform: homeassistant
    id: weather_temperature
    entity_id: weather.accuweather
    attribute: temperature
  - platform: homeassistant
    id: weather_humidity
    entity_id: weather.accuweather
    attribute: humidity
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

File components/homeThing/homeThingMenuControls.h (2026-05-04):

#pragma once
#include <tuple>
#ifdef USE_LIGHT
#include "esphome/components/homeThing/homeThingLightHelpers.h"
#endif

#include "esphome/components/homeThing/homeThingMenuScreen.h"
#include "esphome/components/homeThing/homeThingMenuTitle.h"

namespace esphome {
namespace homething_menu_base {

static const char* const MENU_CONTROLS_TAG = "homething.menu.controls";

enum MenuControlCommand : uint8_t {
  MENU_COMMAND_UP = 0,
  MENU_COMMAND_DOWN = 1,
  MENU_COMMAND_LEFT = 2,
  MENU_COMMAND_RIGHT = 3,
  MENU_COMMAND_SELECT = 4,
  MENU_COMMAND_SCROLL_CLOCKWISE = 5,
  MENU_COMMAND_SCROLL_COUNTER_CLOCKWISE = 6,
  MENU_COMMAND_BACK = 7,
  MENU_COMMAND_OPTION = 8,
  MENU_COMMAND_HOME = 9,
};

class HomeThingMenuControls {
 public:
  static bool editingScrollBack(
      const std::tuple<MenuItemType, EntityBase*, std::string>* entity,
      int menuIndex, bool editing_menu_item) {
    MenuItemType menu_item_type = std::get<0>(*entity);
    switch (menu_item_type) {
      case MenuItemTypeLight: {
#ifdef USE_LIGHT
        auto light = static_cast<light::LightState*>(std::get<1>(*entity));
        int indexOffset = supportsColorTemperature(light) ? 2 : 1;
        if (editing_menu_item && menuIndex == 0 && entity != NULL) {
          HomeThingLightHelpers::decBrightness(light);
          return true;
        } else if (editing_menu_item && menuIndex == 1 && entity != NULL &&
                   supportsColorTemperature(light)) {
          HomeThingLightHelpers::decTemperature(light);
          return true;
        } else if (editing_menu_item && menuIndex == indexOffset &&
                   entity != NULL) {
          HomeThingLightHelpers::decColor(light);
          return true;
        }
#endif
        break;
      }
      case MenuItemTypeNumber: {
#ifdef USE_NUMBER
        if (editing_menu_item) {
          auto number = static_cast<number::Number*>(std::get<1>(*entity));
          number->make_call().number_decrement(false).perform();
          return true;
        }
#endif
        break;
      }
      case MenuItemTypeSelect: {
#ifdef USE_SELECT
        if (editing_menu_item) {
          auto select = static_cast<select::Select*>(std::get<1>(*entity));
          select->make_call().select_previous(false).perform();
          return true;
        }
#endif
        break;
      }
      default:
        break;
    }
    return false;
  }

  static bool editingScrollForward(
      const std::tuple<MenuItemType, EntityBase*, std::string>* entity,
      int menuIndex, bool editing_menu_item) {
    MenuItemType menu_item_type = std::get<0>(*entity);
    switch (menu_item_type) {
      case MenuItemTypeLight: {
#ifdef USE_LIGHT
        auto light = static_cast<light::LightState*>(std::get<1>(*entity));
        int indexOffset = supportsColorTemperature(light) ? 2 : 1;
        if (editing_menu_item && menuIndex == 0 && entity != NULL) {
          HomeThingLightHelpers::incBrightness(light);
          return true;
        } else if (editing_menu_item && menuIndex == 1 && entity != NULL &&
                   supportsColorTemperature(light)) {
          HomeThingLightHelpers::incTemperature(light);
          return true;
        } else if (editing_menu_item && menuIndex == indexOffset &&
                   entity != NULL) {
          HomeThingLightHelpers::incColor(light);
          return true;
        }
#endif
        break;
      }
      case MenuItemTypeNumber: {
#ifdef USE_NUMBER
        if (editing_menu_item) {
          auto number = static_cast<number::Number*>(std::get<1>(*entity));
          number->make_call().number_increment(false).perform();
          return true;
        }
#endif
        break;
      }
      case MenuItemTypeSelect: {
#ifdef USE_SELECT
        if (editing_menu_item) {
          auto select = static_cast<select::Select*>(std::get<1>(*entity));
          select->make_call().select_next(false).perform();
          return true;
        }
#endif
        break;
      }
      default:
        break;
    }
    return false;
  }

  static bool selectLightDetail(
      const std::tuple<MenuItemType, EntityBase*, std::string>* entity,
      int menuIndex, bool editing_menu_item) {
    MenuItemType menu_item_type = std::get<0>(*entity);
    switch (menu_item_type) {
      case MenuItemTypeLight: {
#ifdef USE_LIGHT
        auto light = static_cast<light::LightState*>(std::get<1>(*entity));
        if (light->supports_effects()) {
          int index =
              1 + supportsColorTemperature(light) + supportsColor(light);
          if (menuIndex > index) {
            auto effect = light->get_effects()[menuIndex - index - 1];
            light->turn_on().set_effect(effect->get_name().c_str()).perform();
            return true;
          }
        }
#endif
        return false;
      }
      default:
        break;
    }
    return false;
  }
};
}  // namespace homething_menu_base
}  // namespace esphome

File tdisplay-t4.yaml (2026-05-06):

esphome:
  name: tdisplayt4

esp32:
  board: esp32dev
  framework:
    type: arduino

# WiFi Configuration, uncomment and fill secrets.yaml with wifi_ssid and wifi_password to enable fast connect
captive_portal:

wifi:
  # ssid: !secret wifi_ssid
  # password: !secret wifi_password
  # fast_connect: true

  # Enable fallback hotspot (captive portal) in case wifi connection fails
  ap:
    ssid: "homeThing Fallback Hotspot"

external_components:
  - source: github://landonr/homeThing@main #update_to_head_ref
      # type: local
      # path: components
    refresh: 0s
    components: [homeThingDisplayState, homeThing, homeThingApp, homeThingAppNowPlaying]
  - source:
      type: git
      url: https://github.com/landonr/esphome-components
      ref: main
    refresh: 0s
    components: [
      homeassistant_component,
      homeassistant_media_player,
      media_player_source,
      media_player_source_sonos,
      media_player_source_spotify,
      media_player_source_custom
    ]

packages: # maybe modify: include default ipod controls
  # common
  device_base: github://landonr/homeThing/common/device_base.yaml@main
  remote_package:
    url: https://github.com/landonr/homeThing
    ref: main
    files: [
      common/fonts.yaml, # default font
      common/icon_fonts.yaml, # material icons
      common/settings.yaml, # settings screen
      common/images.yaml, # boot screen image
    ]
    refresh: 0s

substitutions:
  friendly_name: "tdisplayT4"
  large_heavy_font_size: "24"
  large_font_size: "24"
  medium_font_size: "20"
  small_font_size: "18"
  home_thing_logo_size: "64"
  material_font_large_size: "28"
  material_font_small_size: "24"

sensor:
  - platform: rotary_encoder
    filters:
    - throttle: 0.01s
    name: "Rotary Encoder"
    internal: true
    pin_a:
      number: 26
      mode:
        input: true
        pullup: true
    pin_b:
      number: 33
      mode:
        input: true
        pullup: true
    id: rotary
    on_clockwise:
        homething_menu.scroll_clockwise: homeThingMenu
    on_anticlockwise:
        homething_menu.scroll_counter_clockwise: homeThingMenu
  - platform: template
    name: Battery Percent
    id: batteryPercent
    unit_of_measurement: '%'

binary_sensor:
  - platform: gpio
    internal: true
    pin:
      number: 00
      inverted: true
      mode:
        input: true
        pullup: true
    id: sw1
    on_click:
      min_length: 5ms
      max_length: 350ms
      then:
        homething_menu.select: homeThingMenu
    on_multi_click:
    - timing:
        - ON for at least 0.5s
      then:
        homething_menu.option: homeThingMenu
  - platform: gpio
    id: T4_BtnA
    pin:
      number: 39
      inverted: true
    on_click:
      then:
        homething_menu.scroll_counter_clockwise: homeThingMenu
  - platform: gpio
    id: T4_BtnB
    pin:
      number: 37
      inverted: true
    on_click:
      then:
        homething_menu.select: homeThingMenu
  - platform: gpio
    id: T4_BtnC
    pin:
      number: 38
      inverted: true
    on_click:
      then:
        homething_menu.scroll_clockwise: homeThingMenu

spi:
  clk_pin: 18
  miso_pin: 12
  mosi_pin: 23

color: # setup primary accent color
  - id: my_primary_accent
    red_int: 75
    green_int: 45
    blue_int: 209

light: # home assistant lights
  - platform: homeassistant_component
    id: light_desk_lamp
    entity_id: light.desk_lamp
    name: Desk Lamp
  - platform: homeassistant_component
    id: light_all_lights
    entity_id: light.all_lights
    name: All Lights

media_player_source_sonos: # sonos favorite source
  id: sonos

media_player: # home assistant media players
  - platform: homeassistant_media_player
    name: Beam
    entity_id: "media_player.beam"
    id: media_player_beam
    type: speaker
    sources:
      - id: sonos
        type: sonos
  - platform: homeassistant_media_player
    name: TV
    entity_id: "media_player.55_tcl_roku_tv"
    id: media_player_tv
    type: roku
    soundbar:
      speaker: media_player_beam

homeassistant_media_player: # media player menu
  id: media_group_component
  media_players:
    - id: media_player_beam
      type: speaker
    - id: media_player_tv
      type: roku

number: # home assistant number
  - platform: homeassistant_component
    entity_id: number.desk_height_cm
    name: desk height
    id: desk_height_number
    min_value: 61.0
    max_value: 105.0
    step: 1

cover: # home assistant cover
  - platform: homeassistant_component
    entity_id: "cover.megadesk_cover"
    name: "Megadesk"
    id: cover_megadesk

homeThingAppNowPlaying:
  id: now_playing
  media_player_group: media_group_component
  display: my_display
  display_state: display_state_id
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

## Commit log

2022-08-15 rename lights to scenes and add a light switch menu
2022-08-21 change font to iosveka update scrollbar so its more visible add a cap to the battery update readme to include includes
2022-08-22 fix tv not clearing when powered off update readme
2022-08-25 move rotary and button code to its own file support m5stack fire
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2022-08-29 add m5stack fire gifs add images for lights and sensors menu
2022-08-29 clean up sensors image on readme
2022-09-02 fix group menu so it shows the correct group parent use tdisplay right button to go to next media player
2022-09-03 fix spacing and make battery icon optional
    [tdisplayt4.yaml]
2022-09-03 show up to 10 lines on t4 now playing screen fix battery width and spacing
    [tdisplayt4.yaml]
2022-09-15 update at 60fps on lilygo when you scroll fix marquee so it doesn't update on lines that don't marquee fix battery level on tdisplay so it updates quicker and its more accurate keep screen on if its 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
2022-09-15 update logs and fix display not updating while charging
2022-09-16 add battery level and charging for m5stack fire ip5306
2022-09-20 stay on during charging navigate to screens from home assistant show tv app on soundbar when playing tv add tdisplay2 yaml
2022-09-20 add tdisplay t4 fix remote waking up when display is off
    [tdisplayt4.yaml]
2022-09-23 fix playlist getting overwritten update all the globals to substitutions add more accent characters to glyphs
    [tdisplayt4.yaml]
2022-09-23 always update screen if charging show charging on m5stack light
2022-09-23 try to detect when m5stack is on base charger
2022-09-24 add time to status bar make volume level optional move play/pause icon to left side fix rotary option menu not going to menus
    [tdisplayt4.yaml]
2022-10-07 fix crashing on boot
    [tdisplayt4.yaml]
2022-10-08 use material icons instead of pngs
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2022-10-10 customizable accent color! fix material icon scaling show icon for source (youtube, netflix, plex, spotify)
    [tdisplayt4.yaml]
2022-10-10 make drawing time optional fix soundbar not showing tv source add tv icon fix media players not grouping tv and soundbar
    [tdisplayt4.yaml]
2022-10-10 secret for each device
2022-10-10 add group to now playing button menu fix tv now playing title not showing change logs to info update fallback wifi to shorter name sleep m5stick-c add build all script
2022-10-11 add menu roll-over
    when using rotary wheel go to top of menu when end is reached and vice-versa
2022-10-11 add menu_rollover_on to all devices
2022-10-14 load spotify playlists from spotcast sensor use ArduinoJSON for decoding sensors with json add TV to soundbar sources fix soundbar not showing up in media players menu if it was playing tv move frien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
    [tdisplayt4.yaml]
2022-10-15 fix spotify not actually playing tracks because the wrong service was called fixed crash selecting source on speakers without connected tvs added sync_active_player which looks for a new active playe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
    [tdisplayt4.yaml]
2022-10-31 format everything with cpplint
    [CPPLINT.cfg]
2022-11-05 use clang format with esphome's config
    [CPPLINT.cfg]
2022-11-08 Added ability to control switches
2022-11-12 changed swytch to switchObject. Added sample. Change file format to Unix (was dos)
2022-11-20 Put in folder
    [RE Adafruit Rotary Navigation Encoder .step, RE TTGO .step]
2022-11-21 add missing switch case
2022-11-25 add light detail menu to be able to change brightness/color_temp for lights (#15)
    * add light detail menu to be able to change brightness/color_temp for lights
    * add light detail menu to be able to change brightness/color_temp for lights
    * don't show menu if light doesn't support brightness
    * fix duplicate case value
    * make the light know if it supports brightness change
    * change slider design
    * move global vars for light detail to LightGroup class
    * remove default case in selectRootMenu
    * change slider design to two rows (title + slider)
    * make increase/decrease increments adjustable for light brightness and color temperature
    * refactor and cleanup light detail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
    [tdisplayt4.yaml]
2023-01-04 add rgb light slider (#37)
    * split up left and right menu title icons so we can have both!
    * format!!
    * hold center to go to light detail
    * show arrow on group menu menu titles
    * combine slider code into one function
    * code format
    * change rgb light color with slider
    * split up toggle from base menu title
    * draw light switch with color using material icon,
    add light icon to light detail header,
    draw rgb bar for color slider
    * fix rgb light bar offset
    * add white border to left icons when row is selected
    add an extra line of rgb
    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
2023-02-01 New boot sequence - rename project to homething (#38)
    * add new boot menu to psd
    * add new gameboy color style boot screen
    shows wifi and api connection status after animation
    * add header and loading bar to boot sequence
    * fix boot for other devices
    clean up display code, makes device run faster
    * format
    * fix t4 crashing because changing update interval
    clean up animations
    fix loading bar not animating up
    * add skip to boot sequence
    fix bugs with animations resetting when pressing buttons while booting
    clean up bottom bar (loading, media duration, volume) position code
    add a few new characters to glyphs
    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
    [tdisplayt4.yaml]
2023-03-23 add case 1.1b
    [Case_v1.1B_--_Back_Case_--_FDM_--_mm.stl, Case_v1.1B_--_Button_Set_--_FDM_--_mm.stl, Case_v1.1B_--_Front_Case_--_FDM_--_mm.stl]
2023-03-26 add fdm printer case files
    [ESP_v1.1A_Back_Case_-_mm.stl, ESP_v1.1A_Button_Set_-_mm.stl, ESP_v1.1A_Front_Case_-_mm.stl]
2023-04-28 update to home assistant components for easier config (#41)
    * change switch to a native home assistant switch. move code into a cpp file
    * clean up duplicate code
    * clean up namespaces
    * include cpp files and make menu title function static
    * change clang-format line limit to 80 to match cpplint.
    ignore vscode settings
    * format cpp files
    * format files
    * cpplint everything
    * fix light slider
    * change home assistant switch to be based on a switch
    * fix crash with not deleting pointers
    * change switch to a proper component!
    * format files
    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
    [lilygo_tdisplay_ipod_binary_sensor.yaml]
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2023-05-01 add lilygo wiring to readme
2023-05-04 fix now playing menu not working on larger screen devices (#47)
    * fix now playing menu not working on larger screen devices
    * add repeat mode
    * add repeat to settings
2023-05-06 clean up option menu features (#49)
    * clean up option menu features
    * fix display update for option menu
    * make shuffle and repeat options in the display settings
    [tdisplayt4.yaml]
2023-05-11 update docs to include device controls (#50)
    * update docs to include device controls
    * fix numbers and index
    * add wifi to t4
    * fix t4
    * add fonts to getting started
    [tdisplayt4.yaml]
2023-05-16 add lock function (#51)
    * add lock function
    * fix screen not updating on first unlock press
    * add option for locking device
2023-05-23 Lando/optional components (#53)
    * make light group optional
    * make switch optional
    * switch is optional
    * make services optional
    * media player is optional
    * fix build error
    * media player optional and links!
    * fix light
2023-05-24 support internal light along external api light (#54)
    * support internal light along external api light
    * combine light detail control code
    * fix fire not going back in light detail
    * fix 3 button skip boot
2023-05-31 update fire and m5stick c (#55)
    * update fire and m5stick c
    * use remote components
    * use stickc light
    * undo menu changes
    * use remote components for stick
    * update action
    * update action again
    * undo light changes
    * clean up stick c config
    * fix now playing showing app name twice
    * combine groups with component types
    * switch supports internal, add reset switch
    * make text wrap on boot screen
    [tdisplayt4.yaml]
2023-06-05 support custom screens / rooms (#57)
    * add basic settings screen using generic screens
    * add scripts to rooms screen
    * support multiple rooms!
    * make version optional in screens
    * add lights to rooms woot
    * support sensors
    add settings menu with ssid, ip and signal %
    * custom order menu
    fix light detail
    * menu is a tree, so going up menu goes back instead of always to root
    * remove reference to script.h
    * fix group menu going back
    * ifdef switches
    * ifdef light
    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
2023-06-08 fix crash with 3 button controls
2023-06-09 Add Input Number, make editing values generic (#61)
    * add number component
    make light detail code generic so it can be used for cover and number
    * fix light detail header
    * fix crash going up menu
    * fix crash on idle
    * editing numbers works
    * ifdef controls
    * remove light group
    * remove light group from yaml
    * remove light group from other yamls
    * more yaml updates
    * even more yaml updates
    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
    [homeThingMenuControls.h, tdisplayt4.yaml]
2023-06-12 behold, Covers (#58)
    * behold, Covers
    * update yamls
    * fix python
    * use the right components
    * fix editing on cover
    * fix light not appearing
    update screen when values change
    * fix some memory issues,
    move settings to its own yaml
    * update white device
    * add settings yaml
    * pass sources as pointer
    * remove services
    * update boiler room shortcuts lol
    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
    [tdisplayt4.yaml]
2023-06-21 Front and Back Case FDM edit
    No supports needed, buttons not included
    [Jaspercohen_ESP Home Remote 1.3 Bok FDM Edit.stl]
2023-07-05 add i2c to miniencoderc package
2023-07-05 update devices to be examples (#65)
    * move my home stuff into its own repo, change all devices to examples
    * update script and action
    * rename lilygo to tdisplay-s3
    * remove homeConfig from action
    * add back megadesk.h
    * format megadesk
    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
2023-07-07 fix a couple bugs i noticed (#66)
    * fix circle menu being too big in portrait
    fix light detail not updating when editing colour
    updated menu a bit for use in screenshots
    * fix now playing text not showing
    * small readme update
    * use branch for build
    * undo ref change
2023-07-08 add buttons to screen (#67)
    * add buttons to screen
    * ifdef
    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
2023-07-17 hold tdisplay button to go to menu
2023-07-21 support showing entities on home screen (#68)
    * support showing entities on home screen
    * fix light on root not showing icon or selecting detail
    * código de formato
    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
2023-09-06 update to use external file component (#74)
    * update to use external file component
    * update other devices
2023-09-12 Sept update (#75)
    * update mini encoder c to select and hold
    * format axp192
    * dim display while charging
    * clean up marty and add references
    * format binary sensor
    * fix comment
    * update stick configs
    * update ref
    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
    [axp192-geiseri.yaml]
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2023-09-25 Lando/refactor now playing (#77)
    * start refactoring now playing into its own file so we can replace it
    * menu loads now playing items
    * select screens works again
    * select sources is working
    * you can see now playing again
    * fix option menu select
    * header displays the correct stuff
    * fix navigation after selecting a media player
    * fix icons in header
    * fix now playing option menu selection
    * fix tv option menu selection
    * move app stuff into its own class
    * clean up file names
    * i think we can add other apps now
    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
    [m5stack-fire.yaml, tdisplay-s3.yaml, tdisplay-t4.yaml]
2023-10-07 fix switch on home screen not showing icon
2023-10-10 make a switch for dark mode (#81)
    fix light mode issues
2023-10-10 clear option menu if you press a button
2023-10-24 hold switch c button to reboot or select
2023-10-24 use esp32 rmt instead of fastled because of warnings
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2023-11-09 add basic config
    * make super basic config
    * use remote component
    * add basic to ci
    * fix launch image breaking config when not added
    * update boot to not require media players
    * fix dependency
    * fix image dependency
    * use main branch
    [homeThingMenuControls.h]
2023-11-09 add local and roboto shared yamls
    [fonts-roboto.yaml]
2023-11-09 use roboto and local images (#90)
    * use roboto and local images
    * remove external components from s3
    * update a few more devices
    * update font name
    * remove font component
    * fix media player stuff in boot leftover
    * use branch for component
    [m5stack-fire.yaml, tdisplay-s3.yaml, tdisplay-t4.yaml]
2023-11-15 fix errors building with espressif (#92)
    * fix errors building with espressif
    * update branch and add debug
    * fix more warnings and errors
    * change logs to debug
    * fix all but light warnings
    * fix more debug errors
    * cpplint
    * move source to its own file
    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
    [debug.yaml, homeThingMenuControls.h]
2023-11-15 fix sensor not showing value
2023-11-17 add s3 dxf and kicad pcb (#87)
    * add s3 dxf and kicad pcb
    * organize case files and add kicad file
    * add s3 case stl and f3z files
    * change led to 5mm and add transistor to it
    * fix ground not connecting to bottom pin
    * add capacitor to i2c
    * update cap to be between 3v and gnd for i2c
    * update track thickness
    * reroute transistor
    * add yaml for gpio extender
    * Update README.md
    * more readme update
    * Update README.md
    * more readme updates!
    [Adafruit Rotary Navigation Encoder.step, Case_v1.1B_--_Back_Case_--_FDM_--_mm.stl, Case_v1.1B_--_Button_Set_--_FDM_--_mm.stl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]
2023-12-06 show light effects in light details (#94)
    * show light effects in light detail
    * fix light sliders not drawing dot in the correct position
    * fix scrolling with double line rows
    [homeThingMenuControls.h]
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2023-12-08 Notifications (#95)
    * add notifications that show over the ui
    * fix log
    [lilygo_tdisplay_ipod_binary_sensor_pcf.yaml]
2023-12-12 update ir blaster on pcb
    [s3-B_Cu.gbr, s3-B_Mask.gbr, s3-B_Paste.gbr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]
2023-12-30 move launch image to boot config (#96)
    * move launch image to boot config
    * update configs to match new schema
    * fix weather app
    * fix more devices
    * clean up stick sleep
    * add stick backlight pin
    * revert branch
    * use branch
    * change display menu ifdef to use now playing
    * revert branch
    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
    [debug.yaml, m5stack-fire.yaml, tdisplay-s3.yaml]
2024-01-12 5000 mAh battery case (#97)
    * 5000 mAh battery case
    Case design to fit the T-display with a 5000 mAh battery.
    The original buttons are used.
    * Renamed files to be a bit more descriptive
    * added readme file + main components picture
    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
    [Case_v1.0_--_Back_Case_--_FDM_--5000mAh.stl, Case_v1.0_--_Front_Case_--_FDM_--5000mAh.stl.stl, HT--Button Set--SLA -- v1.3.stl]
2024-01-16 add now playing image (#98)
    * add now playing image
    * replace branch reference with current branch
    * replace external component ref
    * update s3 ref
    * fix now playing bottom bar position
    * fix margin on bottom menu
    * move now playing settings into now playing app
    * update s3 example to use pcb and media player image
    * add ref for components
    * fix megadesk now playing config
    [debug.yaml, m5stack-fire.yaml, tdisplay-s3.yaml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]
2024-01-23 fix now playing bottom menu not showing when option is set (#99)
    * fix now playing bottom menu not showing when option is set
    * fix megadesk config
    * update s3 now playing to package
    * add logger.yaml
    [tdisplay-s3.yaml]
2024-02-06 update s3 readme
    [s3 case back fdm.stl, s3 case back sls.stl, s3 case back.stl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]
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2024-03-21 update case files
    [s3 case back fdm.stl, s3 case back sls.stl, s3 case back.stl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]
2024-03-28 Added Some i2c That should work. (#106)
    * Addis Some i2c That should work.
    * Changed all i2c files to "seesaw" for clarity
    * added seesaw referances to original tdisplay-s3 yaml
    * added to comments to show what is pfc and what is seesaw. Also removed extra tdisplay yaml
    * Change package location back to orriginal
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2024-04-05 update s3 case increase clearances between front and back case add support behind pcb by buttons
    [s3 case back.stl, s3 case front fdm.stl, s3 case front sls.stl]
2024-04-05 Cleanup remote packages (#109)
    * update package ref for current branch
    * undo seesaw change
    * test using new file
    * update ci action
    * undo ci change
    * add note about images needing pillow
    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
2024-04-05 Fix s3 config (#110)
    * update s3 config
    * add voice assistant yaml
    [tdisplay-s3.yaml]
2024-04-06 generate esphome devices automatically (#111)
    * generate esphome devices automatically
    * no message
    * no message
    * no message
    * no message
    * no message
    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
2024-04-07 Improv wifi (#112)
    * captive portal for wifi config
    * dont create face secrets
    * debug
    * move s3 stuff to its own folder
    * update local build to replace with branch
    * add improv wifi to boot
    * update ap text
    * update every config to use device base wifi
    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
    [debug.yaml, lilygo_tdisplay_ipod_binary_sensor_pcf.yaml, lilygo_tdisplay_ipod_binary_sensor_seesaw.yaml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]
2024-04-22 update case files to match orders
    [s3 case front sls.stl]
2024-04-25 Boot crash fix (#115)
    * fix menu selection when skipping boot, and crash on now playing without player
    * update launch image url
    * add device base light
    * update wifi settings for ipod
    * add comments
    * remove #update_to_head_ref
    [debug.yaml, m5stack-fire.yaml]
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2024-05-11 fix voice assistant notifications
    [tdisplay-s3.yaml]
2024-05-26 pcb updates add 3v + symbol to LED add pcf8574n up symbol make resistor gap larger
    [s3-B_Cu.gbr, s3-B_Mask.gbr, s3-B_Paste.gbr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]
2024-06-10 add 3v to capacitor, update image (#126)
    [s3-B_Cu.gbr, s3-B_Mask.gbr, s3-B_Paste.gbr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]
2024-06-20 June24 (#128)
    * add ota platform
    * remove logger from device base
    * add i2c package
    * upgrade build action version
    * upgrade esphome builder version
2024-06-21 add all the weather states (#125)
    * add all the weather states
    * add other weather images
    * add partly cloudy and lightning
    * remove duplicate lightning case
    * update s3 weather config
    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
2024-06-22 Fan menu item and component (#124)
    * add new fan menu item
    * add fan images
    * show fan as switch
    * fix toggle on fan
    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
2024-07-01 Show sensor value before name. add menu item renaming (#129)
    * update sensor menu item so value is first. add name as optional param
    * add option to rename menu items
    * fix fan menu item
    * fix fan menu item
    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
    [homeThingMenuControls.h, tdisplay-s3.yaml]
2024-07-01 add charge and data port to pcb (#130)
    * add charge and data port to pcb
    * update pcb image
    [s3-B_Cu.gbr, s3-B_Mask.gbr, s3-B_Paste.gbr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]
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2024-07-05 Sensor value on right of screen (#134)
    * move sensor value to right of menu item
    * add unit of measurement
    * add missing break
    * build debug with current branch
    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
    [debug.yaml]
2024-07-05 add active player sensor (#133)
    * add active player sensor
    * remote https from readme and update docs
2024-09-24 fix i2c address
2024-11-27 fix missing glyphs
    [fonts-roboto.yaml]
2024-11-27 add invert colors to t4
    [tdisplay-t4.yaml]
2024-11-27 add invert colors to m5stack fire
    [m5stack-fire.yaml]
2024-11-27 invert colors in debug
    [debug.yaml]
2025-02-28 fix images for s3 config (#145)
    [tdisplay-s3.yaml]
2025-08-27 update esphome runner (#147)
    * update esphome runner
    * fix rmt channel
    * add home assistant states to device base
    ---------
    [sidelight.yaml, tdisplay-s3.yaml]
2025-08-27 ignore venve and logger (#148)
    * ignore venve and logger
    * add logger to failing devices
    * remove stickcplus
    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
    [tdisplay-s3.yaml]
2026-05-04 fix(s3): restore tdisplay-s3 build
    Vendor homeassistant_component into this repo and replace the
    removed sensor filter debounce usage so the config builds on
    current ESPHome again.
    [tdisplay-s3.yaml]
2026-05-04 refactor(build): unvendor HA components
    Pin device configs to the shared esphome-components fix instead of carrying homeassistant_component in this repo.
    [debug.yaml, m5stack-fire.yaml, tdisplay-s3.yaml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]
2026-05-04 build(esphome): bump shared fix pin
    [debug.yaml, m5stack-fire.yaml, tdisplay-s3.yaml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]
2026-05-04 fix(build): track esphome head
    [debug.yaml, homeThingMenuControls.h, m5stack-fire.yaml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]
2026-05-04 fix(config): route builds to branch
    [m5stack-fire.yaml, tdisplay-t4.yaml]
2026-05-06 fix builds (#153)
    * fix(s3): restore tdisplay-s3 build
    * refactor(build): unvendor HA components
    * build(esphome): bump shared fix pin
    * fix(build): track esphome head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
    [debug.yaml, homeThingMenuControls.h, m5stack-fire.yaml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]
2026-10-25 fix: limit S3 LED strip RMT symbols so the IR transmitter can start
